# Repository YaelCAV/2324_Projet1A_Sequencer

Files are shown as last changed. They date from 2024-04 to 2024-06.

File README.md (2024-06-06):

# Projet-Sequenceur
> On souhaite créer un séquenceur musical qui émet des notes sur demande de l'utilisateur. Les notes doivent être variées et configurables, par exemple on souhaite pouvoir modifier leur hauteur, le nombre de répétitions par minute (bpm), et combiner les notes.
Pour cela on utilise sur conseil de l'un de nos professeurs un générateur de son programmable de Comodore 64 (dénomée MOS 6581) sortie en 1982.
La documentation de cette puce est facile d'accès et les possibilités qu'elle offrent satisfont nos exigences.
Comme mode de récupération du signal de sortie nous avons finalement choisi de proposer une sortie MIDI et Jack, il n'y a pas de haut-parleur intégré à notre séquenceur. L'alimentation de notre machine se fera par ailleurs via un port USB-C.

# Equipe
* Yael CAVAILLE-VOISIN
* Alexis NAUD
* Benoit LOMBARD
* Guilhem BOULARAN
* Louis GEORGE
> Rajouter vos github, linked in, etc...

# Journal de bord
> Déroulé séance par séance

## Séance 1 création du git, rédaction du cahier des charges et du plan, révision du cahier des charges.
## Séance 2 rendu du diagramme d'architecture, et des 3 bons de commande de composants, révision du cahier des charges et recherche des composants.
## Séance 3 CAO avec Kicad, changement de composants (boutons et LEDs RGB, hauts-parleurs, ampli audio).
## Séance 4 fin de conception du PCB et routage complet.
## Séance 5 récupération des composants et soudure, conception 3D, Architecture du code
## Séance 6 soudure + résolution des problèmes (d'empreinte des boutons-LED RG au lieu de RB via des PCB-adaptateurs imprimés à l'ENSEA), conception 3D
## Séance 7 soudure + résolution de problèmes, code, conception 3D
## Séance 8 soudure + résolution de problèmes, code, conception 3D
## Séance 9 code, présentation en séance, màj des livrables, résolution de problèmes liés au PCB et au processeur !
## Séance 10 code, création, compilation et vérification des livrables.

# Livrables
## PCB
> Présentation du schéma (grandes lignes) + PCB

## Code
> Architecture de votre code

## Rendu final
> Video ici de votre projet

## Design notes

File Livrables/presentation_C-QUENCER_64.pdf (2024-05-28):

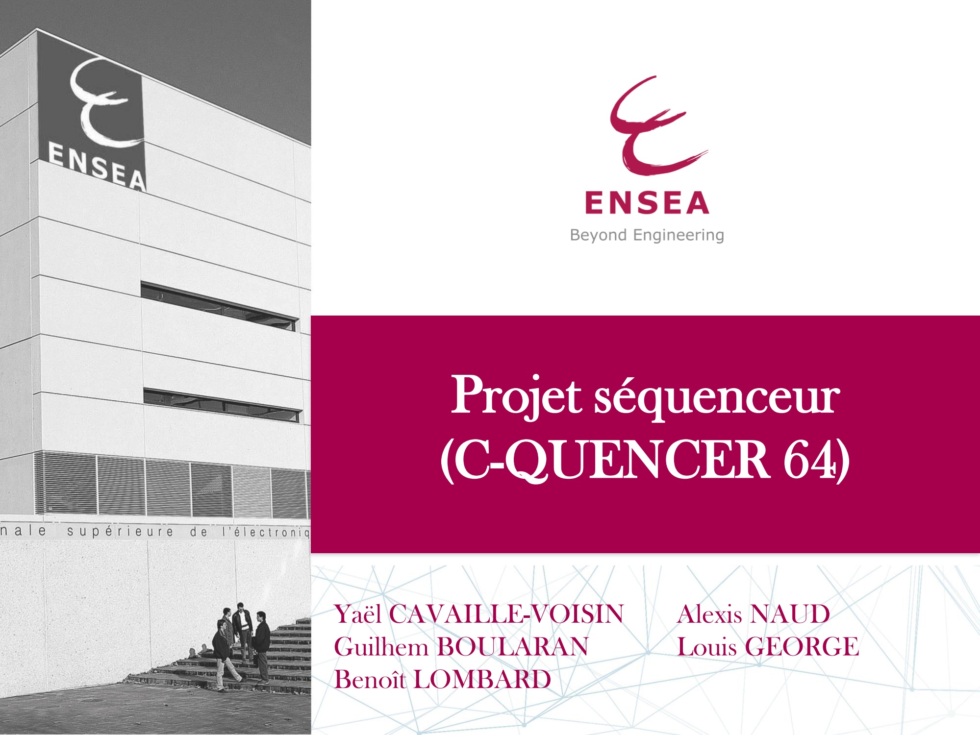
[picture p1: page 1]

# Projet séquenceur (C-QUENCER 64)

Yaël CAVAILLE-VOISIN | Alexis NAUD
Guilhem BOULARAN | Louis GEORGE

# Benoît LOMBARD

# TITRE DE PARAGRAPHE

# Concept & objectifs :

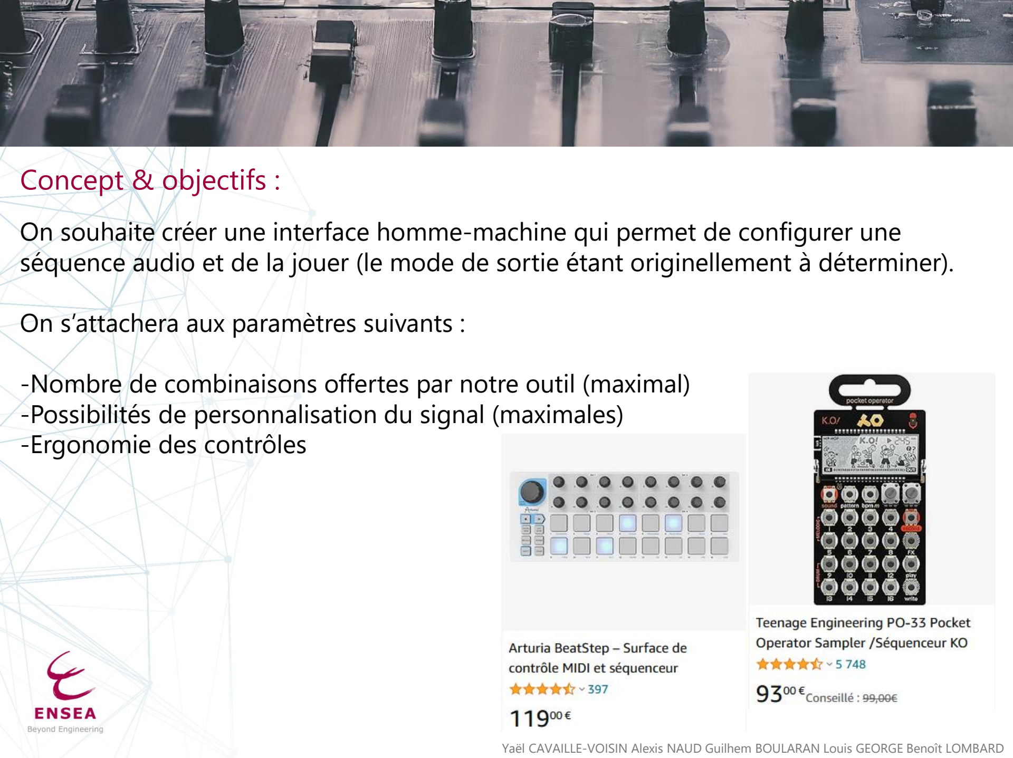
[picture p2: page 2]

# On souhaite créer une interface homme-machine qui permet de configurer une

séquence audio et de la jouer (le mode de sortie étant originellement à déterminer).

# On s’attachera aux paramètres suivants :

# -Nombre de combinaisons offertes par notre outil (maximal) -Possibilités de personnalisation du signal (maximales) -Ergonomie des contrôles

Yaël CAVAILLE-VOISIN Alexis NAUD Guilhem BOULARAN Louis GEORGE Benoît LOMBARD

# Cahier des charges du C-QUENCER 64 :

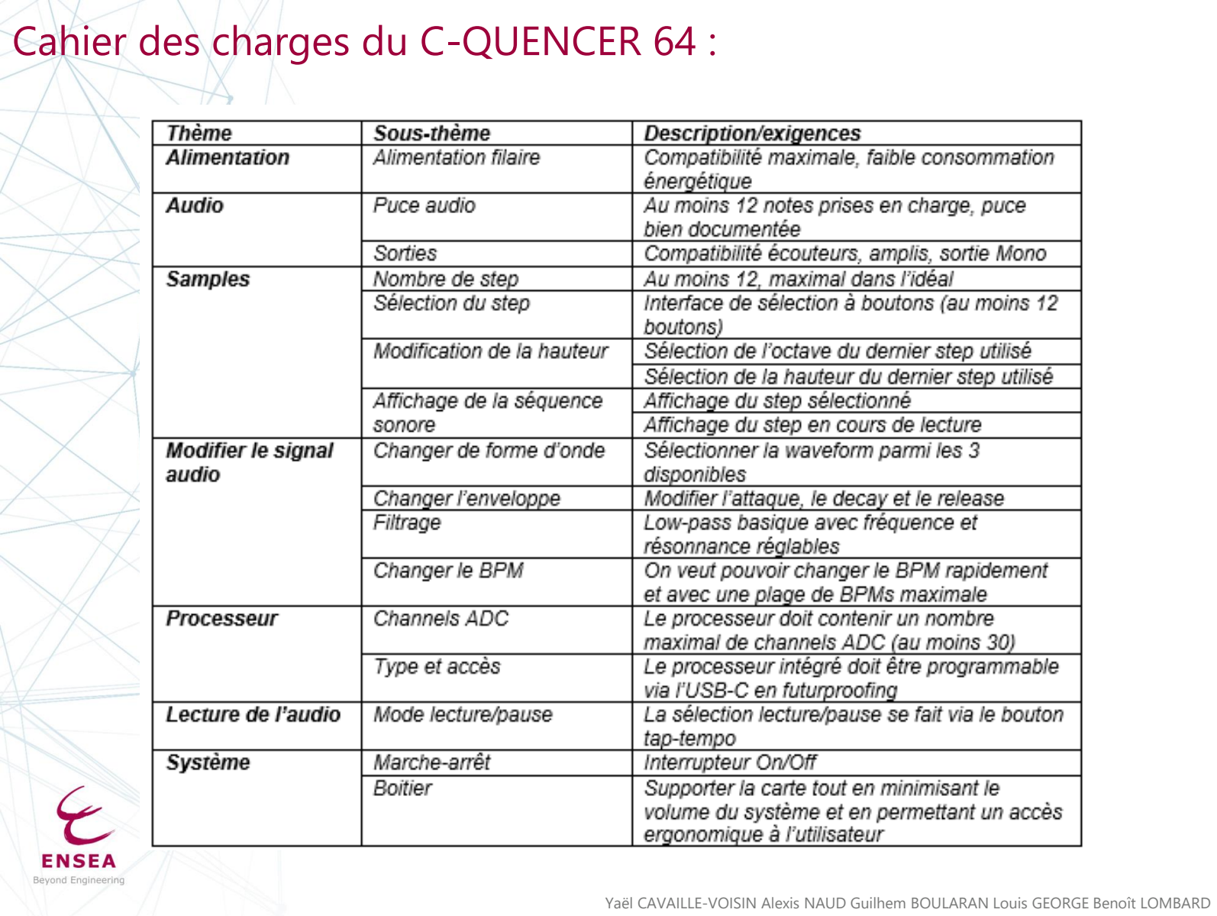
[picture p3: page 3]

# Répartition des Tâches & Déroulement du Projet :

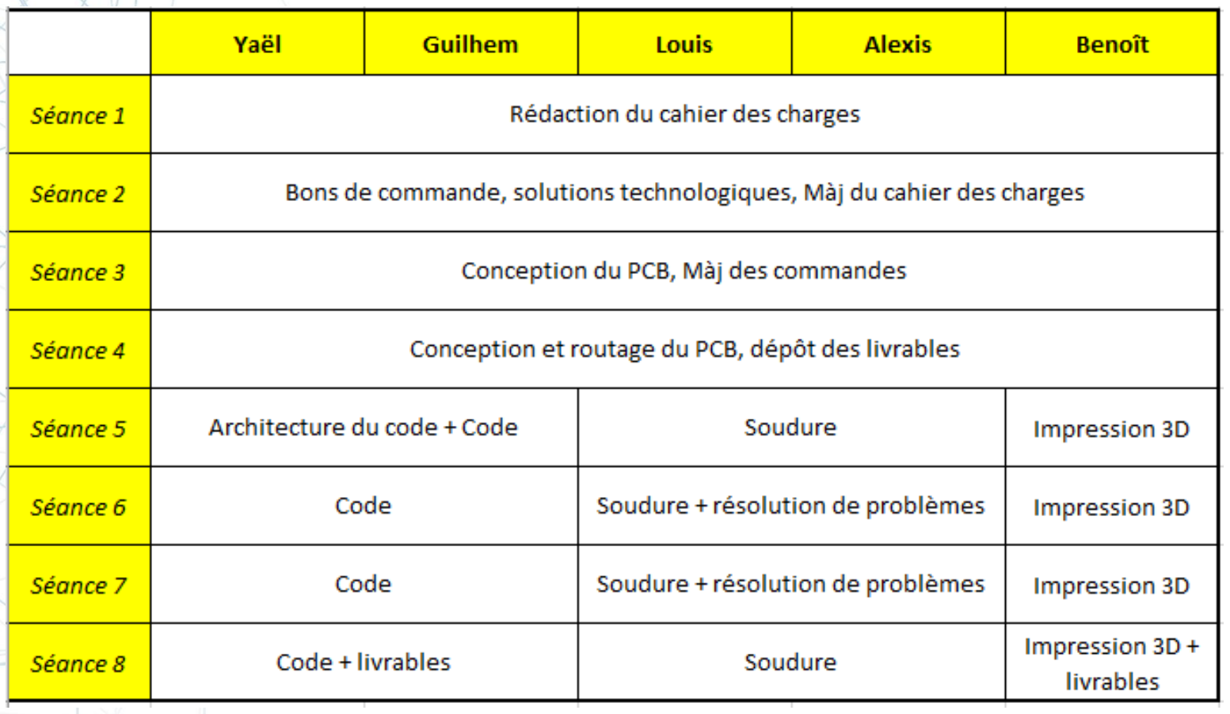
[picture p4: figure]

# Solutions techniques retenues pour le C-QUENCER 64 :

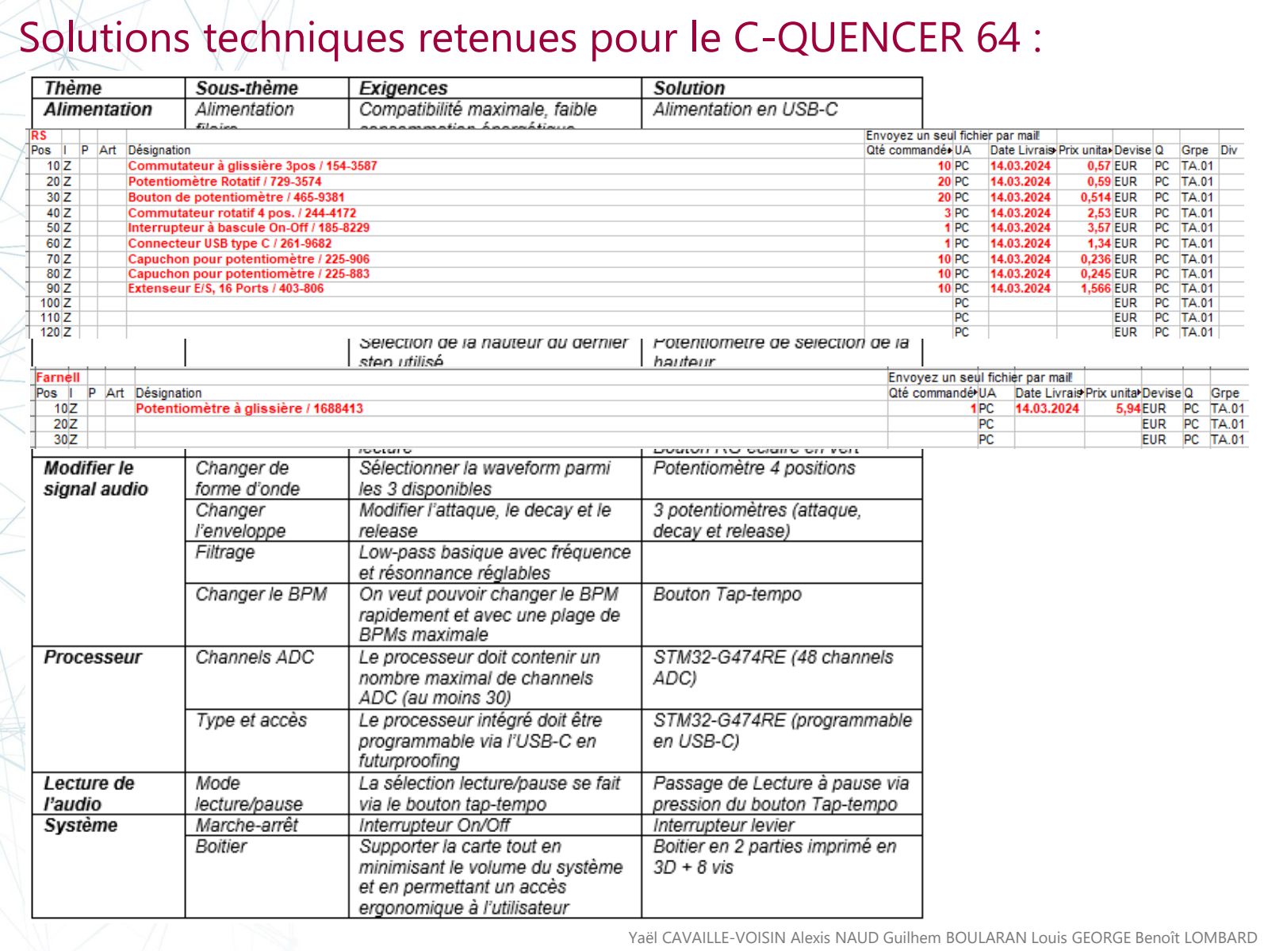
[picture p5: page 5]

# PCB 1/2 :

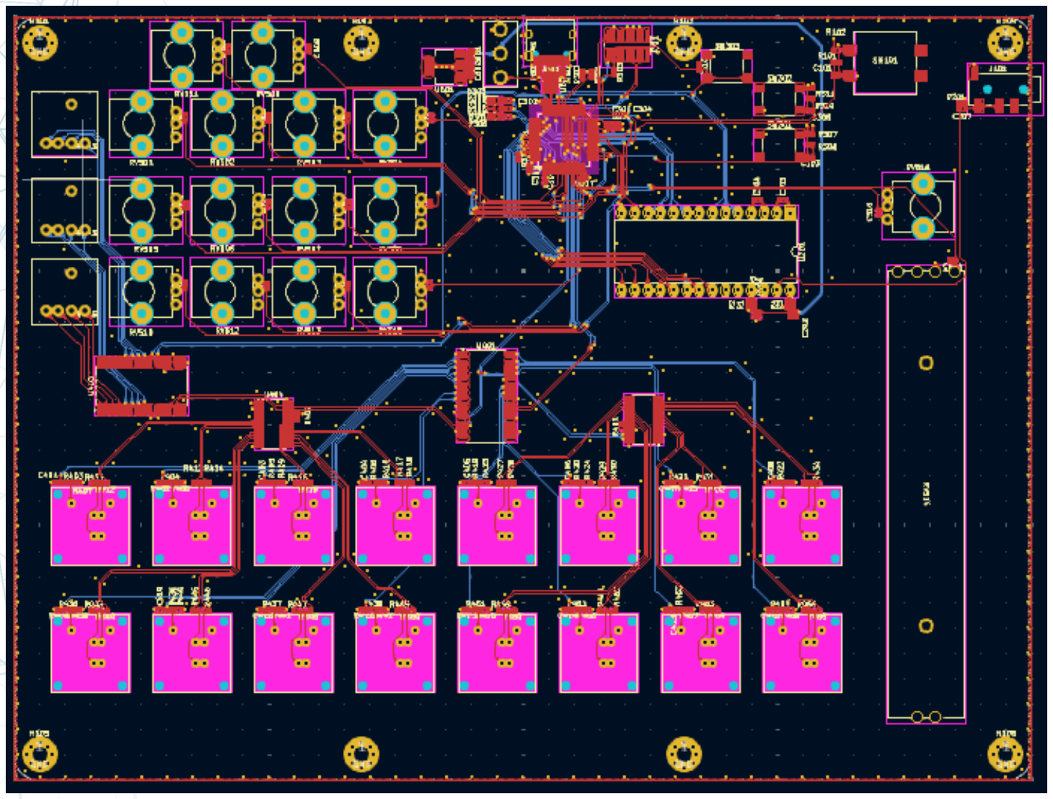
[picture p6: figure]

# PCB 1/2 :

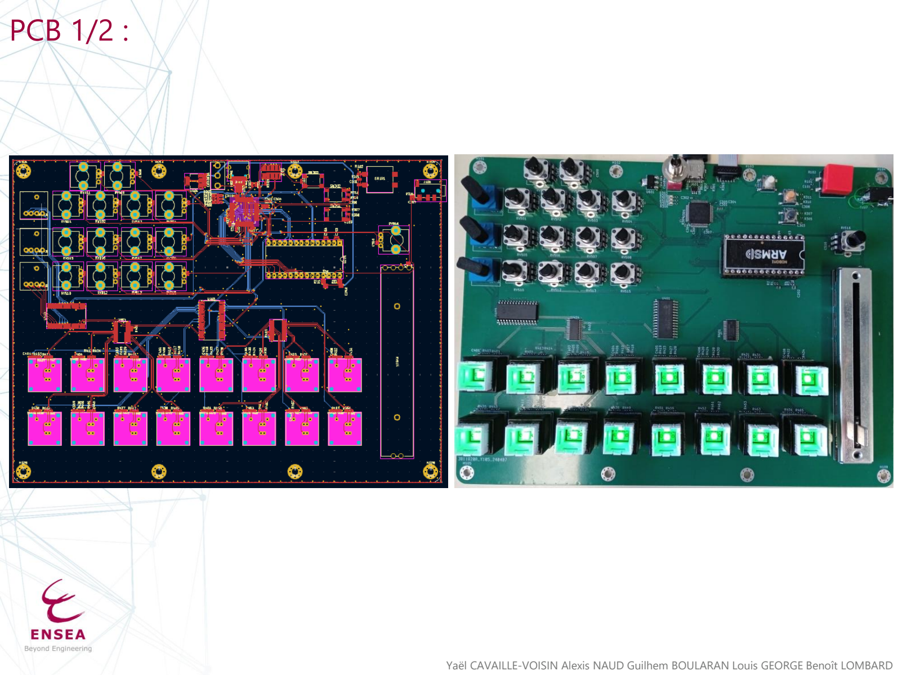
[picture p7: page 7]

# PCB 1/2 :

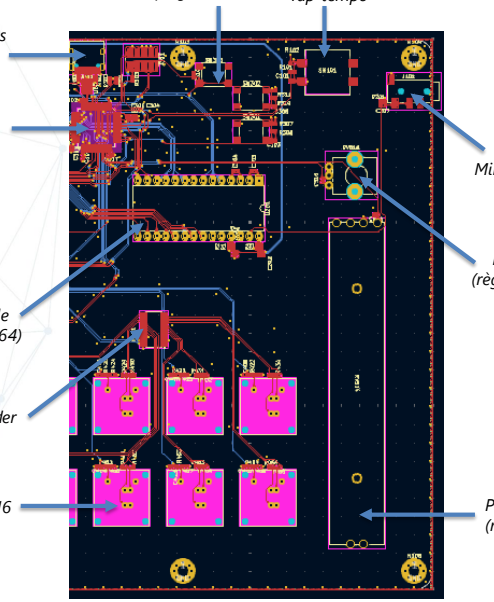
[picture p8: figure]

## Potentiomètre linéaire (règlage de la hauteur)

## Potentiomètre (règlage de l’octave)

## Sortie Mini-Jack 3.5

## Bouton Tap-tempo

### Boutons de programmation x3

## Alimentation et accès programmation du processeur (USB-C)

## Processeur STM32-G474RE

## Puce audio ARMSID simulation de MOS 6581 (Comodore 64)

## GPIO expender

## Bouton-LED RG x16

# PCB 2/2 :

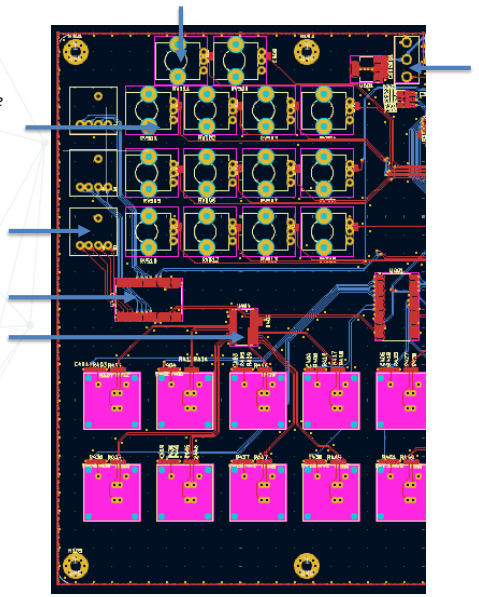
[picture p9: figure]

## Interrupteur général

## Sélecteur de waveformes (potentiomètre à crans x3)

## Potentiomètres d’enveloppe (attack, decay, release)

## Potentiomètres de filtre (fréquence et résonnance)

## LED Driver

## GPIO Expender

# Code :

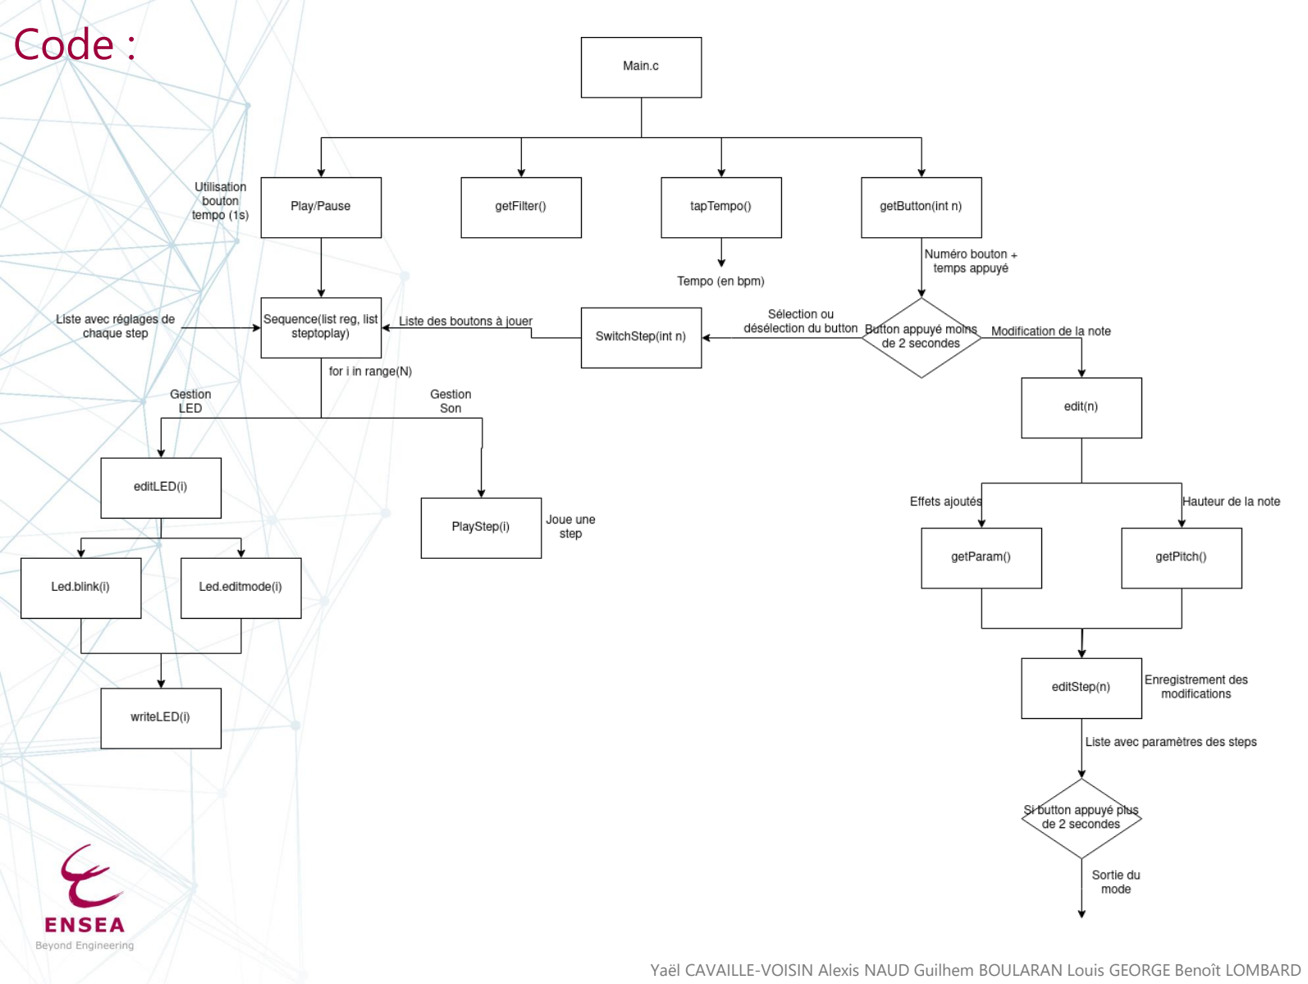
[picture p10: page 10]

# Code :

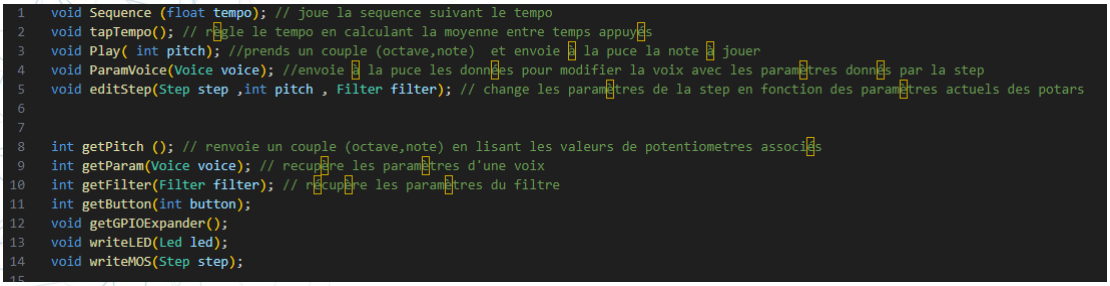
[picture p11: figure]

# Défis et solutions :

# - Erreur de WÜRT Electronik dans les commandes : bouton-LED RG au lieu de RB

donc problème d’empreinte avec le PCB.

# On a soudé des PCB-adaptateurs imprimés à l’ENSEA entre le PCB et les boutons-

LED RG.

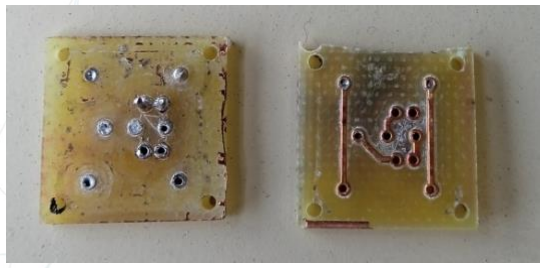
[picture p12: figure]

# - Quelques difficultés lors de la programmation, car les tensions des broches de la

puce audio ne correspondaient pas à ce qui est attendu d’après la documentation.

# Perspectives :

# - Manque de temps par rapport à la complexité du code à réaliser, il parrait difficile

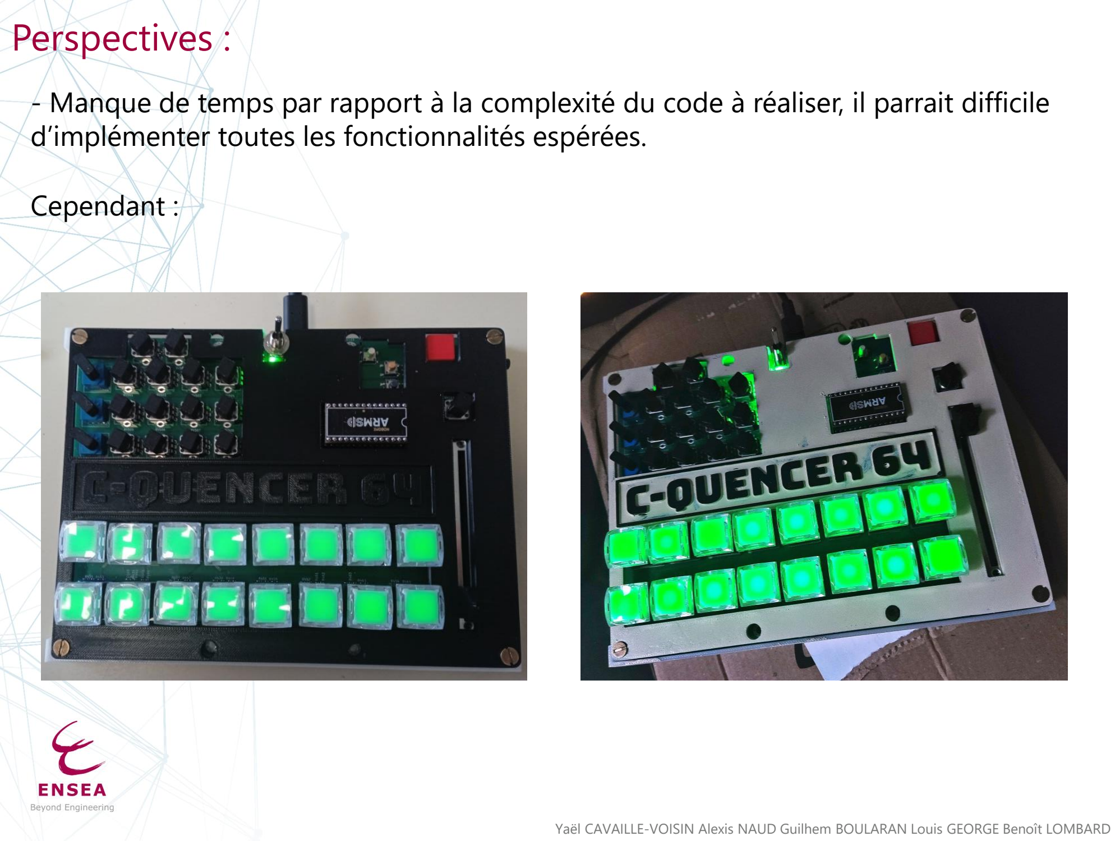
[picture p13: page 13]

d’implémenter toutes les fonctionnalités espérées.

# Cependant :

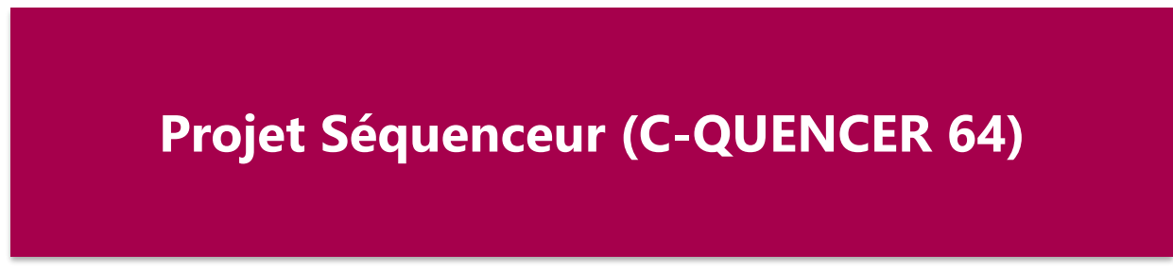
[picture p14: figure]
Projet Séquenceur (C-QUENCER 64)

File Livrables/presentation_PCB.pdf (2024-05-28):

## Présentation du PCB :

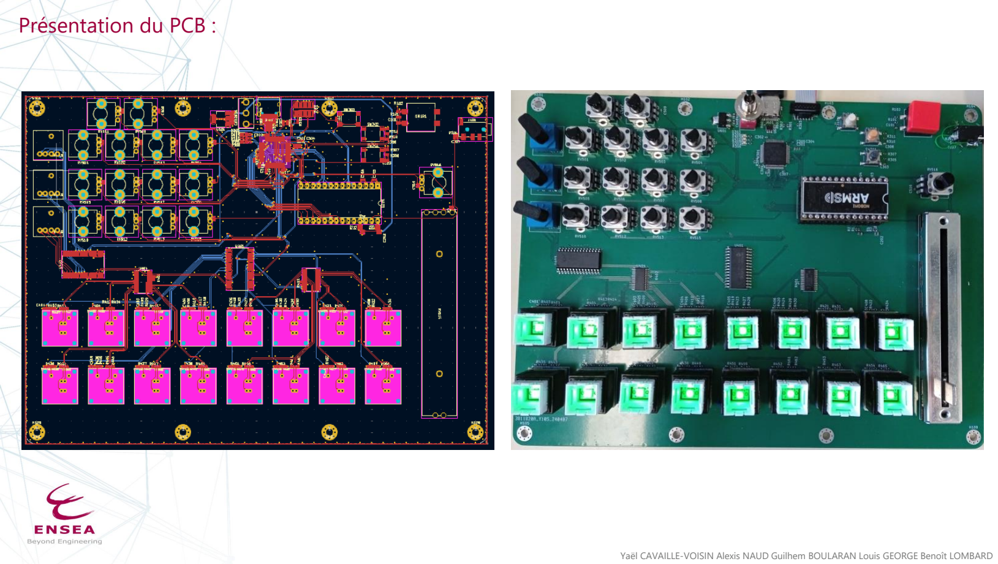
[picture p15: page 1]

Yaël CAVAILLE-VOISIN Alexis NAUD Guilhem BOULARAN Louis GEORGE Benoît LOMBARD

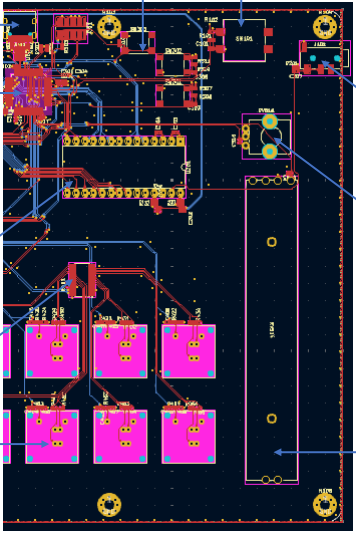
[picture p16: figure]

Potentiomètre linéaire
(règlage de la hauteur)

Potentiomètre
(règlage de l’octave)

Sortie
Mini-Jack 3.5

Bouton
Tap-tempo

Boutons de
programmation x3

Alimentation et accès
programmation du
processeur (USB-C)

Processeur
STM32-G474RE

Puce audio
ARMSID simulation de
MOS 6581 (Comodore 64)

GPIO expender

Bouton-LED RG x16

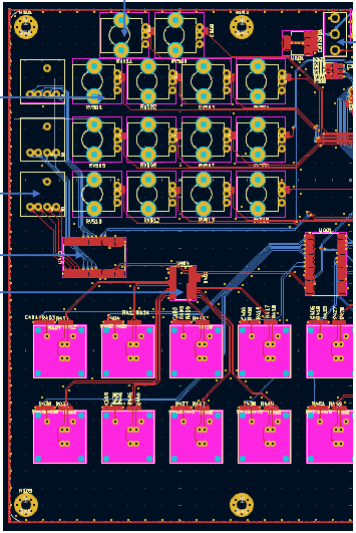
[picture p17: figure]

Interrupteur général

Sélecteur de waveformes
(potentiomètre à crans x3)

Potentiomètres d’enveloppe (attack, decay, release)

Potentiomètres de filtre
(fréquence et résonnance)

LED Driver

GPIO Expender

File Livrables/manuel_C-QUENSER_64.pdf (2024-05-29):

### Manuel d’utilisation du C-QUENCER 64

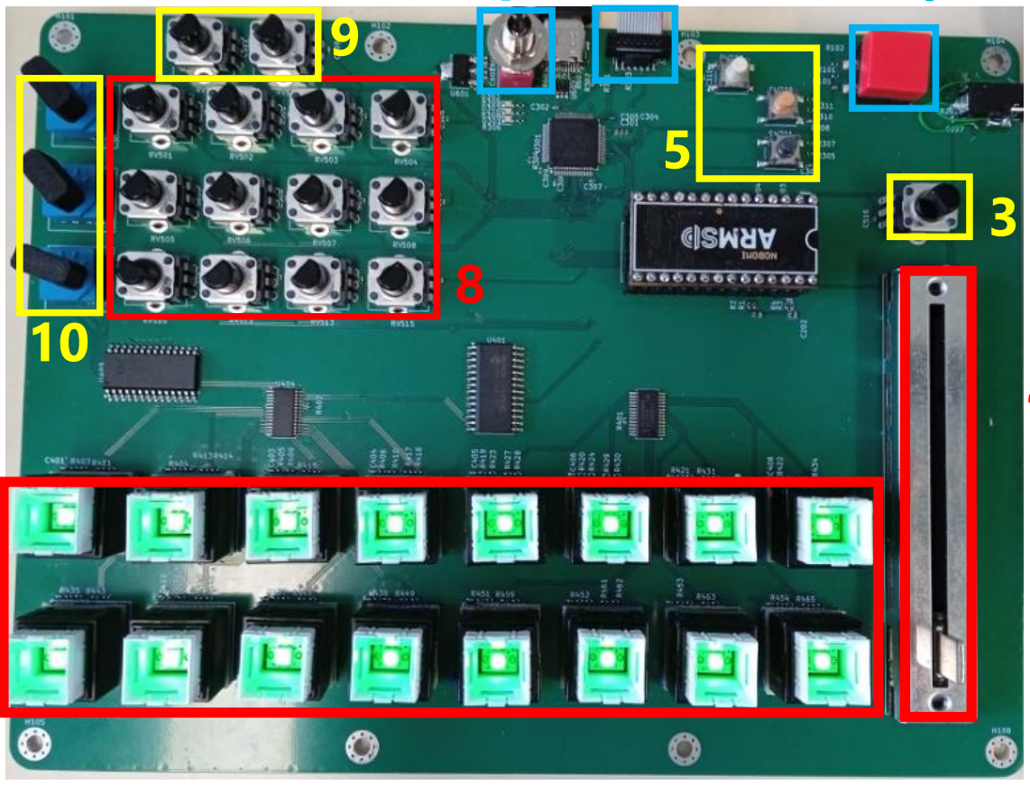
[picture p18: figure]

1. 16 Boutons d’activation des steps, l’appui permet d’activer ou désactiver les steps.
2. Potentiomètre linéaire de réglage de la hauteur du step sélectionné.
3. Potentiomètre d’octave, permet de régler l’octave du step sélectionné.
4. Bouton tap-tempo : calcule le temps moyen entre deux activations du bouton et en extrait le BPM qui cadencera la séquence de notes. Un seul appui sur le bouton tap-tempo permet de passer du mode lecture au mode pause (et inversement), lors d’un nouvel appui.
5. 3 Boutons servant à la programmation du processeur (ne sont pas destinés à l’acheteur).
6. Port USB-C servant à l’alimentation et à la programmation du processeur.
7. Interrupteur général du séquenceur.
8. 12 Potentiomètres de sélection des valeurs du : pulse-width (rapport cyclique) (utilisable uniquement pour le signal créneau), attack, decay, et release (de gauche à droite suivant une ligne). Chaque ligne représente une voie, la puce audio peut donc prendre en charge 3 voies simultanément.
9. 2 Potentiomètres de configuration du filtre passe-bas : à gauche le potentiomètre détermine la fréquence de coupure, à droite il détermine la résonnance.
10. Potentiomètre à crans permettant la sélection du type de forme d’onde (Sinus, créneau, triangle ou bruit).

1

2

4

7 6

Utilisation du C-QUENSER 64 :

1. Activer un step via un appui sur l’un des 16 boutons poussoirs «RGB» (1).
2. Configurer les formes d’ondes de ce step via les potentiomètres à crans (10) puis régler le band-width, attack, decay et release (8). Régler l’octave (3) et la hauteur (2), l’ordre dans lequel sont faits ces réglages est indifférent, ils seront appliqués au dernier step qui a été activé uniquement.
3. Répéter les étapes 1 et 2 pour chaque step souhaité et pour le nombre de steps souhaités.
4. On peut ensuite changer le BPM (4) et/ou paramétrer un filtre passe-bas via les 2 potentiomètres (9), ces paramètres sont des paramètres globaux qui sont appliqués à tous les steps activés. Les paramètres Globaux peuvent aussi être appliqués ou configurés en amont, cela ne changera pas la production finale, l’utilisateur est invité à employer la méthode qu’il juge la plus performante.

L’utilisation du C-QUENCER 64 nécessite qu’il soit alimenté via l’USB-C (6).

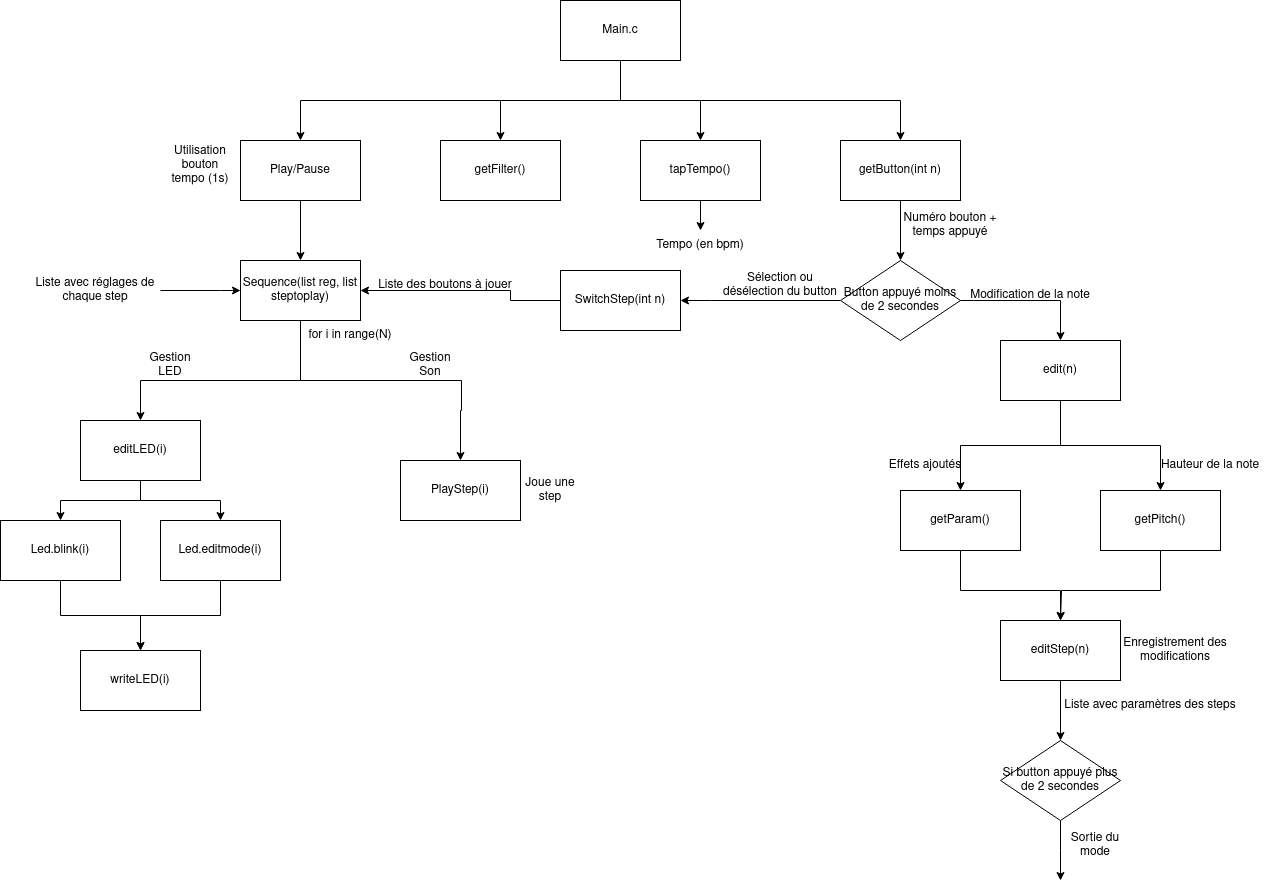
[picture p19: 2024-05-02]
Fonctionnement_sequencer.png

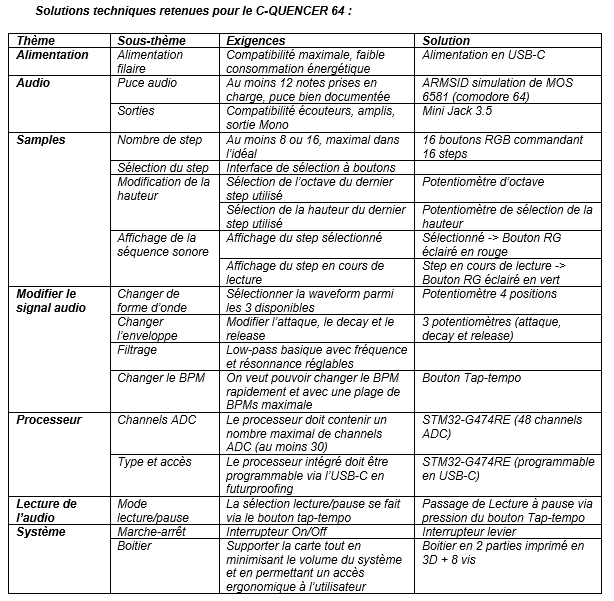
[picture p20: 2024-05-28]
Livrables/cahier_des_charges.png

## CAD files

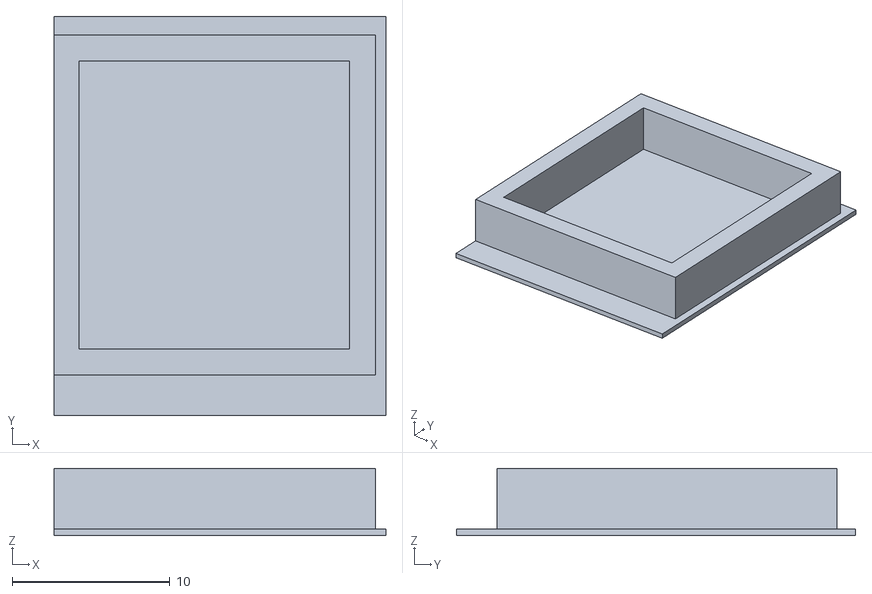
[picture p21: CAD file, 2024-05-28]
3D/cache_sequenceur v3.stl
21.0 x 25.3 x 4.25

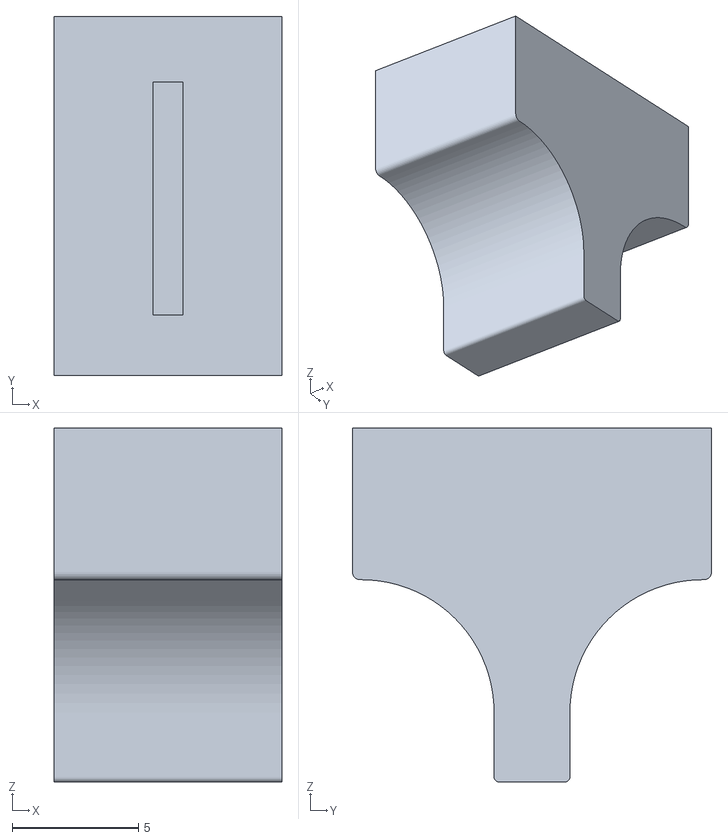
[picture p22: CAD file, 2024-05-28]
3D/capuchon_potar_lineaire_sequenceur v7.stl
9.00 x 14.2 x 14.0

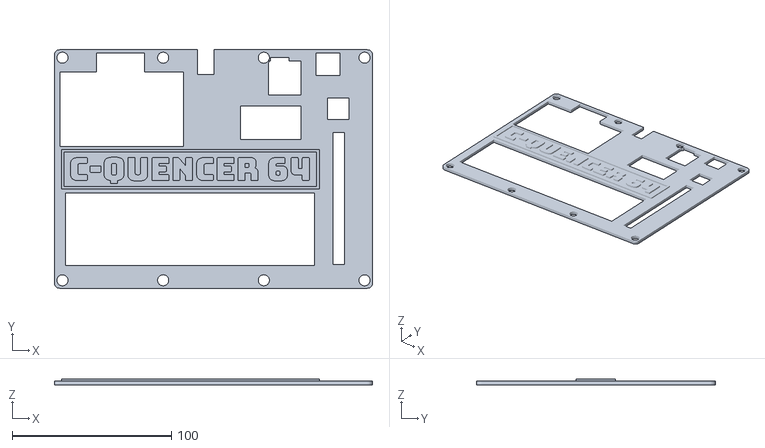
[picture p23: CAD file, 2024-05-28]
3D/couvercle_sequenceur v16.stl
200.0 x 150.0 x 4.00

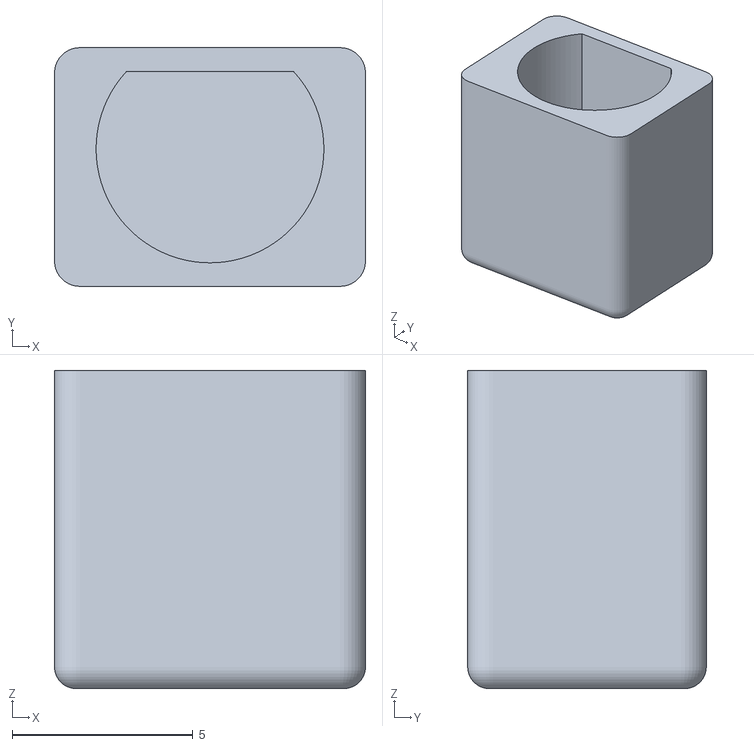
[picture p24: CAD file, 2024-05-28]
3D/potentio_sequenceur v3.stl
8.60 x 6.60 x 8.80

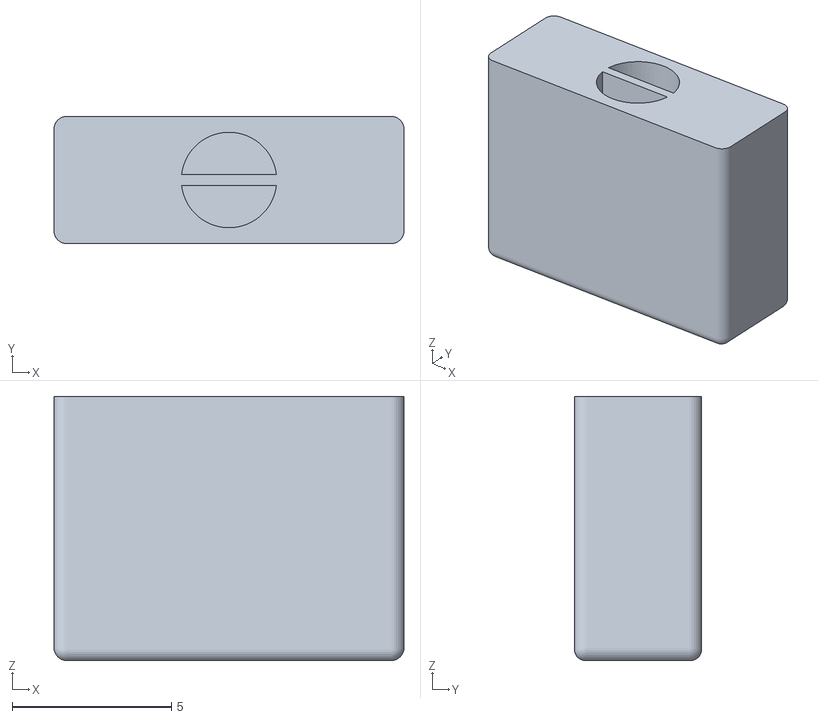
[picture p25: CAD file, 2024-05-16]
3D/capuchon_wave_sequenceur v2.stl
11.0 x 4.00 x 8.30

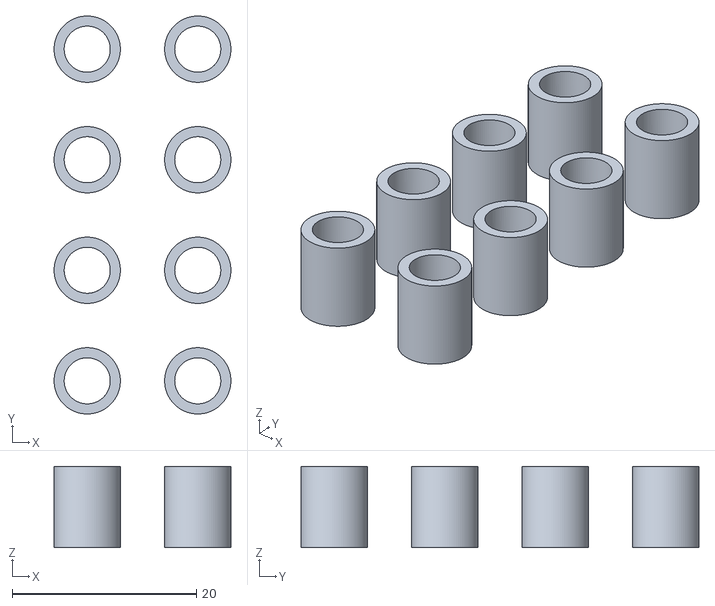
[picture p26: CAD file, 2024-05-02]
3D/Joints sequenceur.stl
19.2 x 43.2 x 8.80

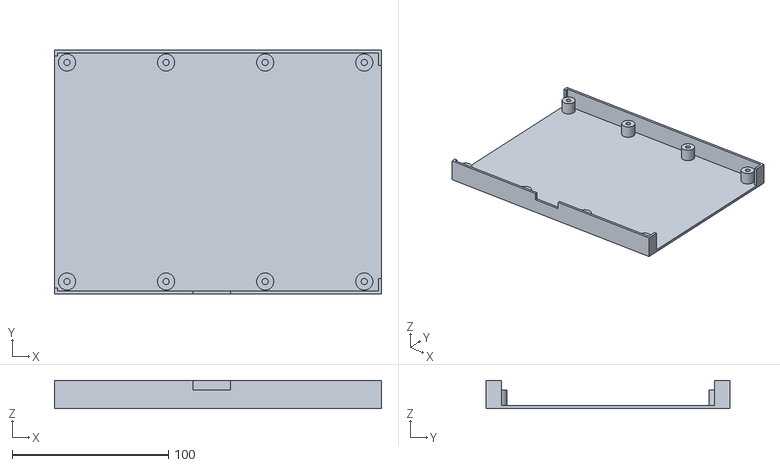
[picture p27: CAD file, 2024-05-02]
3D/Boitier_sequenceur v6.stl
209.0 x 156.0 x 18.0

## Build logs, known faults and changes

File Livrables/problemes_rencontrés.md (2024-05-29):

# Problèmes C-QUENCER_64 :
## Au niveaux des I2C : On a un inversé SCL et Sdata
-> Solution = On coupe les pistes et on rajoute des fils pour échanger les pistes.
## Aucun signal Horloge ne sort de la broche PG10 de la puce audio, au lieu de cela un signal Horloge sort de la broche PA8 lorsqu’on programme PG10 comme sortie du signal d’horloge.
-> Solution = on coupe la piste liée à PA8 et on récupère le signal Horloge via un fil.
## Impossible d’implémenter un DFU car il manque une patte sur la puce audio.
## On a refait un socket sur la puce car 2 pattes avaient été cassées.

# Améliorations pour C-QUENCER_64v2 :
## L’ajout d’un signal de synchronisation IN-OUT (clock externe), ce signal définit le BPM de notre retour.
## Ajout d'un bouton de sélection des pistes, car pour le moment on doit appuyer sur le tap-tempo pour sélectionner le signal à modifier, ce qui met sur pause le retour.
## Utiliser des touches de clavier mécanique «cherry-MX» comme bouton RGB, en mettant des Leds RGB dedans. Afin de réduire le coût des boutons, et d’optimiser la course des boutons (meilleure ergonomie).
## Bouton tap-tempo : changer le modèle du bouton pour un bouton avec une pression d’enclanchement moins importante.
## Inclure un haut-parleur sans amplificateur dans la prochaine version du PCB, il lui sera fourni le même signal que la sortie mini-jack 3.5, l’intérêt est d’avoir un retour imédiat de la sortie (savoir si on a un son ou non).
## Inclure dans la prochaine version du PCB, une led qui clignotte à même fréquence que le BPM.
## Inclure dans la prochaine version du PCB, une sortie MIDI, pour répondre à la forte demande consomateur.

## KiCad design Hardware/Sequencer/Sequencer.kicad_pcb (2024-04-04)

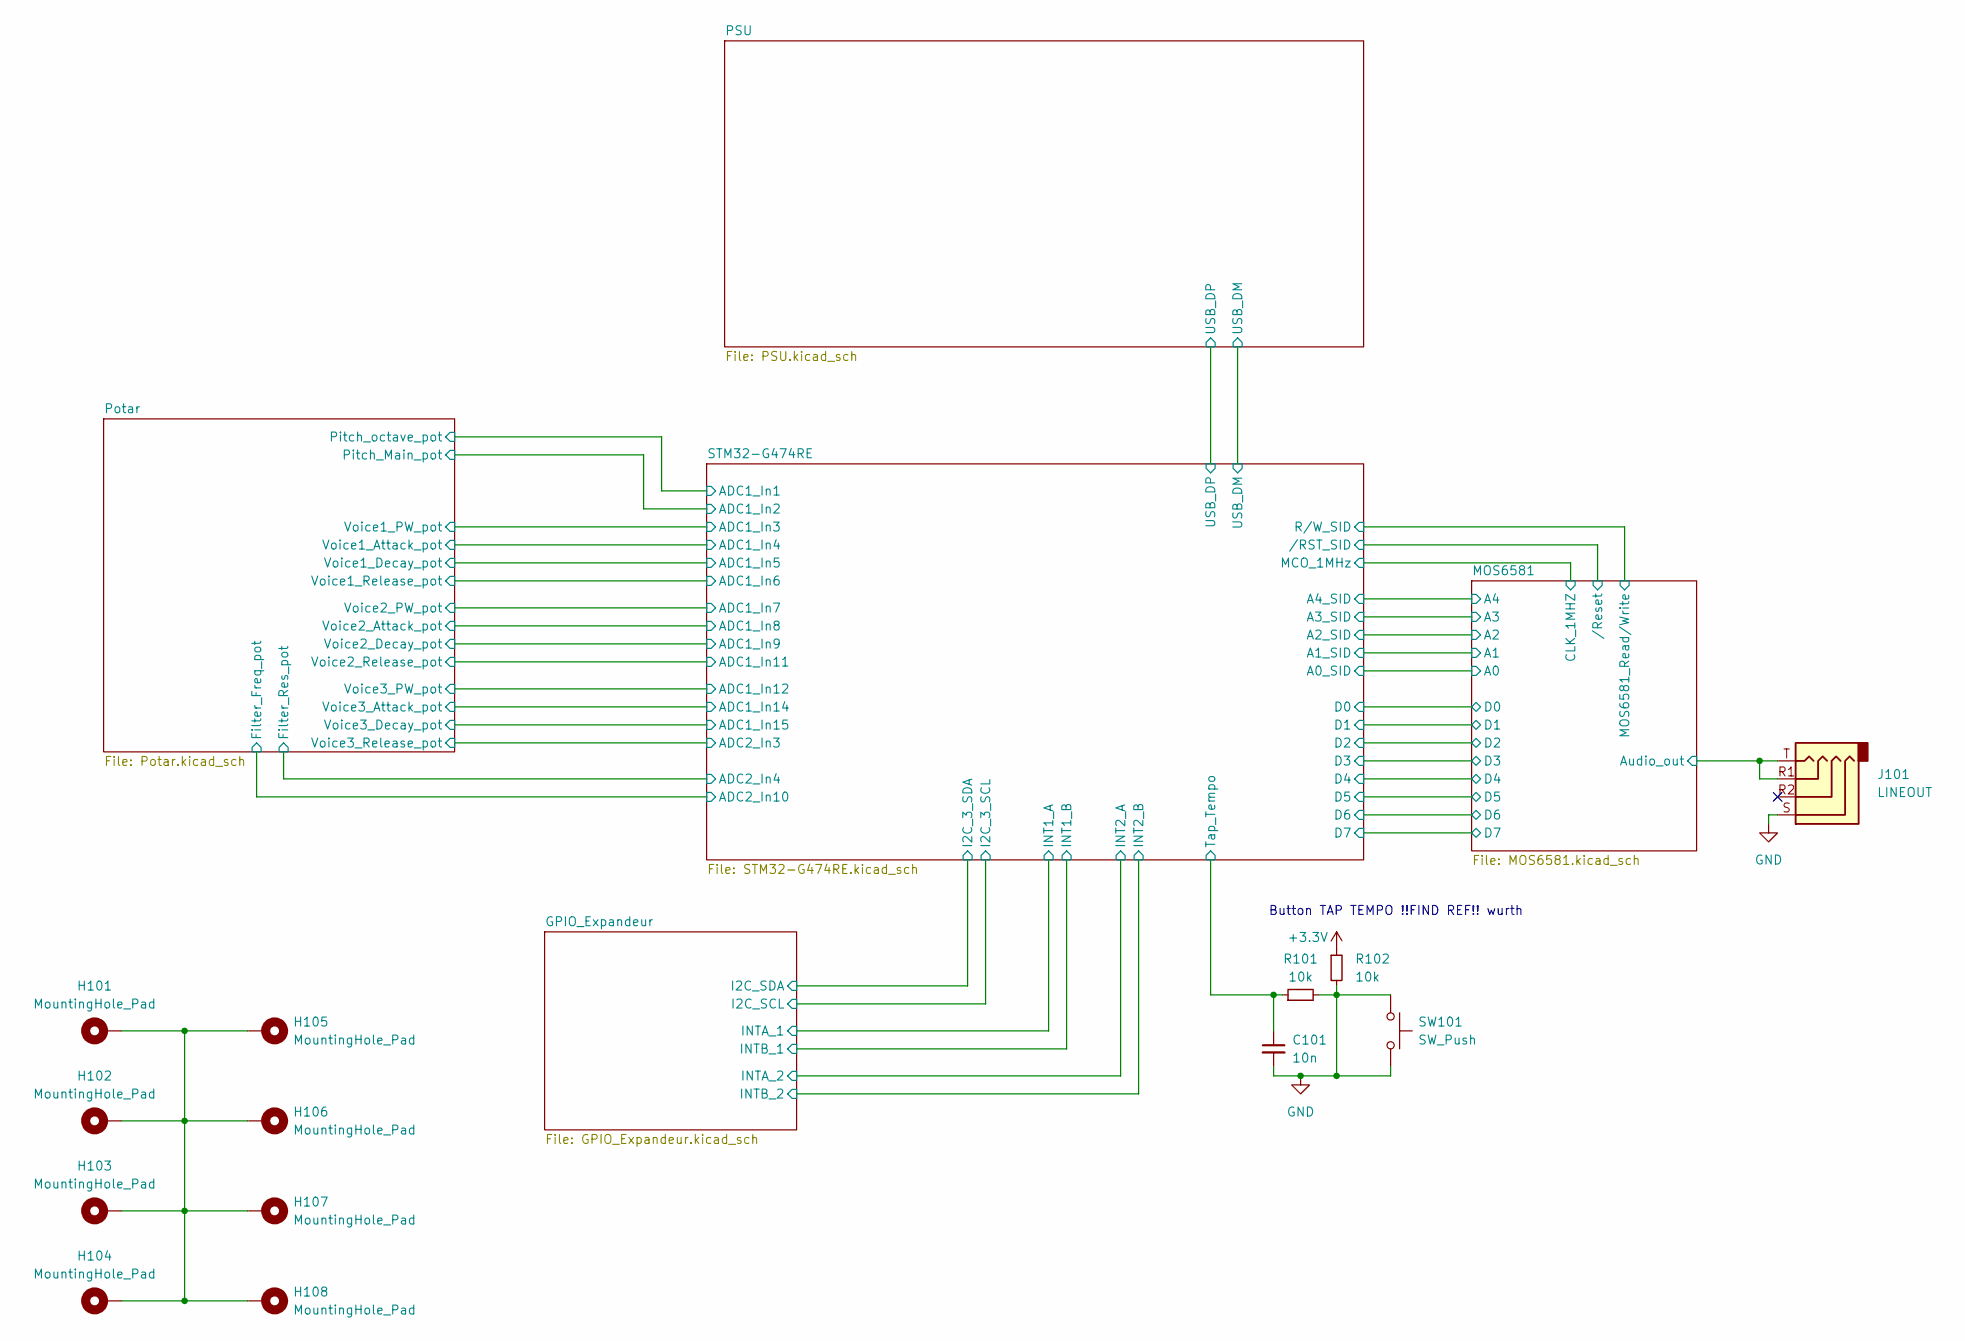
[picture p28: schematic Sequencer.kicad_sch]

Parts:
C101: 10n; C_0402_1005Metric
H101, H102, H103, H104, H105, H106, H107, H108: MountingHole_Pad; MountingHole_3.2mm_M3_Pad_Via
J101: LINEOUT; Jack_3.5mm_PJ320D_Horizontal; LCSC Part C431535
R101, R102: 10k; R_0402_1005Metric
SW101: SW_Push; SMT Push Button 12x12

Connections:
+3.3V: R102.1; also elsewhere on the board
/MOS6581/Audio_out: J101.R1, J101.T; also elsewhere on the board
/STM32-G474RE/Tap_Tempo: C101.1, R101.1; also elsewhere on the board
GND: C101.2, J101.S, R101.2, R102.2, SW101.1, SW101.2; also elsewhere on the board
unnamed: H101.1, H102.1, H103.1, H104.1, H105.1, H106.1, H107.1, H108.1

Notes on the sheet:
Button TAP TEMPO !!FIND REF!! wurth

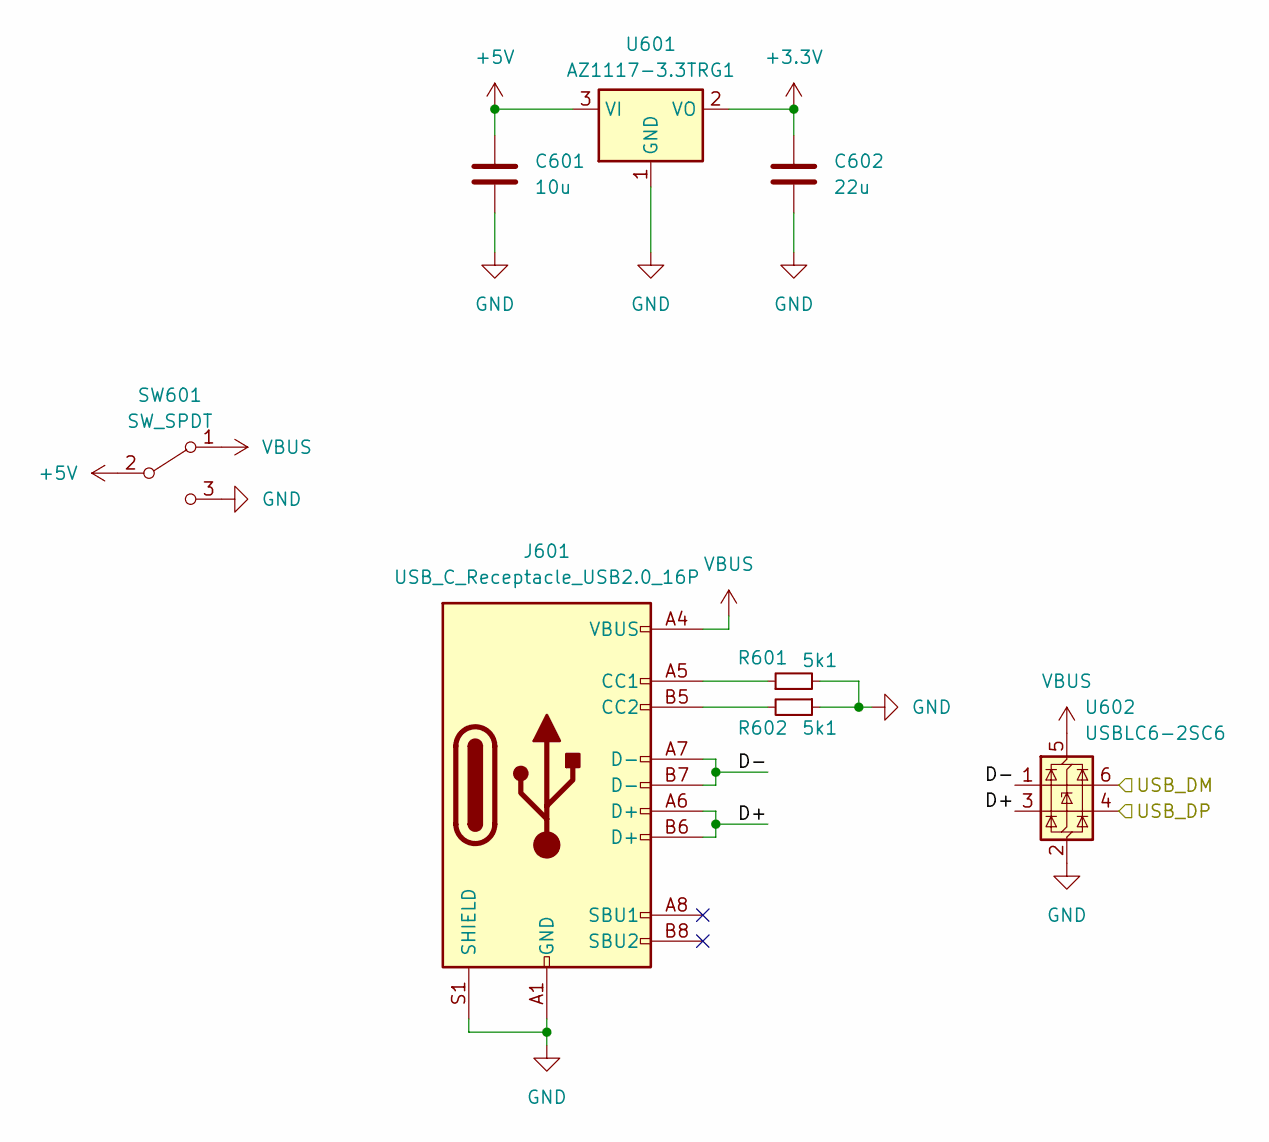
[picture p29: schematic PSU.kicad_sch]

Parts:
C601: 10u; C_0603_1608Metric
C602: 22u; C_0603_1608Metric
J601: USB_C_Receptacle_USB2.0_16P; USB_C_Receptacle_HRO_TYPE-C-31-M-12
R601, R602: 5k1; R_0402_1005Metric
SW601: SW_SPDT; 472121010111; MPN 472121010111
U601: AZ1117-3.3TRG1; SOT-223-3_TabPin2
U602: USBLC6-2SC6; SOT-23-6

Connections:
+3.3V: C602.1, U601.2 (VO); also elsewhere on the board
+5V: C601.1, SW601.2 (B), U601.3 (VI); also elsewhere on the board
/PSU/D+: J601.A6 (D+), J601.B6 (D+), U602.3 (I/O2)
/PSU/D-: J601.A7 (D-), J601.B7 (D-), U602.1 (I/O1)
/PSU/USB_DM: U602.6 (I/O1); also elsewhere on the board
/PSU/USB_DP: U602.4 (I/O2); also elsewhere on the board
GND: C601.2, C602.2, J601.A1 (GND), J601.A12 (GND), J601.B1 (GND), J601.B12 (GND), J601.S1 (SHIELD), R601.2, R602.1, SW601.3 (C), U601.1 (GND), U602.2 (GND); also elsewhere on the board
unnamed: J601.A5 (CC1), R601.1
unnamed: J601.B5 (CC2), R602.2
VBUS: J601.A4 (VBUS), J601.A9 (VBUS), J601.B4 (VBUS), J601.B9 (VBUS), SW601.1 (A), U602.5 (VBUS)

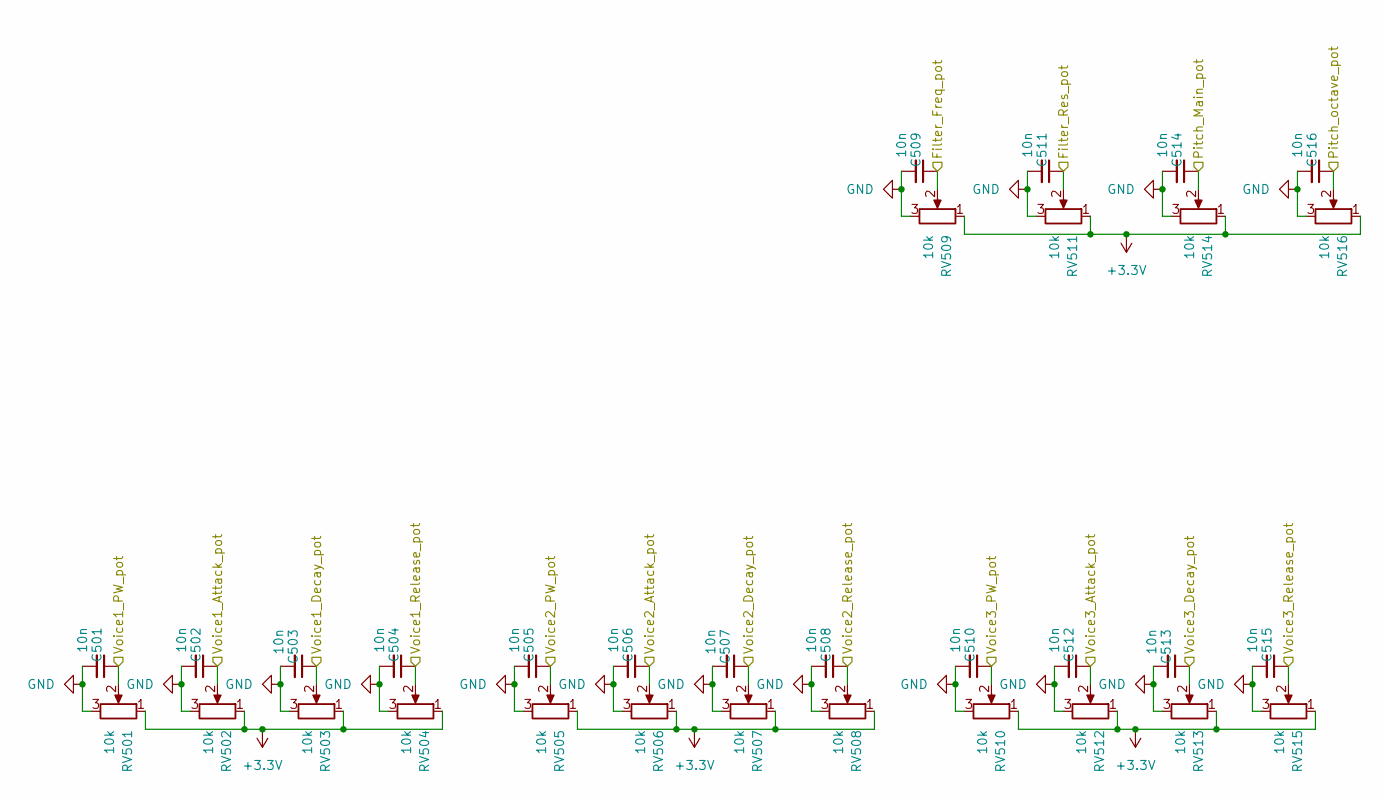
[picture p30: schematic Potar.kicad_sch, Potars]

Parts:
C501, C502, C503, C504, C505, C506, C507, C508, C509, C510, C511, C512, C513, C514, C515, C516: 10n; C_0402_1005Metric
RV501, RV502, RV503, RV504, RV505, RV506, RV507, RV508, RV509, RV510, RV511, RV512, RV513, RV515, RV516: 10k; Potentiometer_Alps_RK09K_Horizontal_CORRECTED
RV514: 10k; PTB6044-2010BPA103_BRN

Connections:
+3.3V: RV501.1, RV502.1, RV503.1, RV504.1, RV505.1, RV506.1, RV507.1, RV508.1, RV509.1, RV510.1, RV511.1, RV512.1, RV513.1, RV514.1, RV515.1, RV516.1; also elsewhere on the board
/Potar/Filter_Freq_pot: C509.1, RV509.2; also elsewhere on the board
/Potar/Filter_Res_pot: C511.1, RV511.2; also elsewhere on the board
/Potar/Pitch_Main_pot: C514.1, RV514.2; also elsewhere on the board
/Potar/Pitch_octave_pot: C516.1, RV516.2; also elsewhere on the board
/Potar/Voice1_Attack_pot: C502.1, RV502.2; also elsewhere on the board
/Potar/Voice1_Decay_pot: C503.1, RV503.2; also elsewhere on the board
/Potar/Voice1_PW_pot: C501.1, RV501.2; also elsewhere on the board
/Potar/Voice1_Release_pot: C504.1, RV504.2; also elsewhere on the board
/Potar/Voice2_Attack_pot: C506.1, RV506.2; also elsewhere on the board
/Potar/Voice2_Decay_pot: C507.1, RV507.2; also elsewhere on the board
/Potar/Voice2_PW_pot: C505.1, RV505.2; also elsewhere on the board
/Potar/Voice2_Release_pot: C508.1, RV508.2; also elsewhere on the board
/Potar/Voice3_Attack_pot: C512.1, RV512.2; also elsewhere on the board
/Potar/Voice3_Decay_pot: C513.1, RV513.2; also elsewhere on the board
/Potar/Voice3_PW_pot: C510.1, RV510.2; also elsewhere on the board
/Potar/Voice3_Release_pot: C515.1, RV515.2; also elsewhere on the board
GND: C501.2, C502.2, C503.2, C504.2, C505.2, C506.2, C507.2, C508.2, C509.2, C510.2, C511.2, C512.2, C513.2, C514.2, C515.2, C516.2, RV501.3, RV502.3, RV503.3, RV504.3, RV505.3, RV506.3, RV507.3, RV508.3, RV509.3, RV510.3, RV511.3, RV512.3, RV513.3, RV514.3, RV515.3, RV516.3; also elsewhere on the board

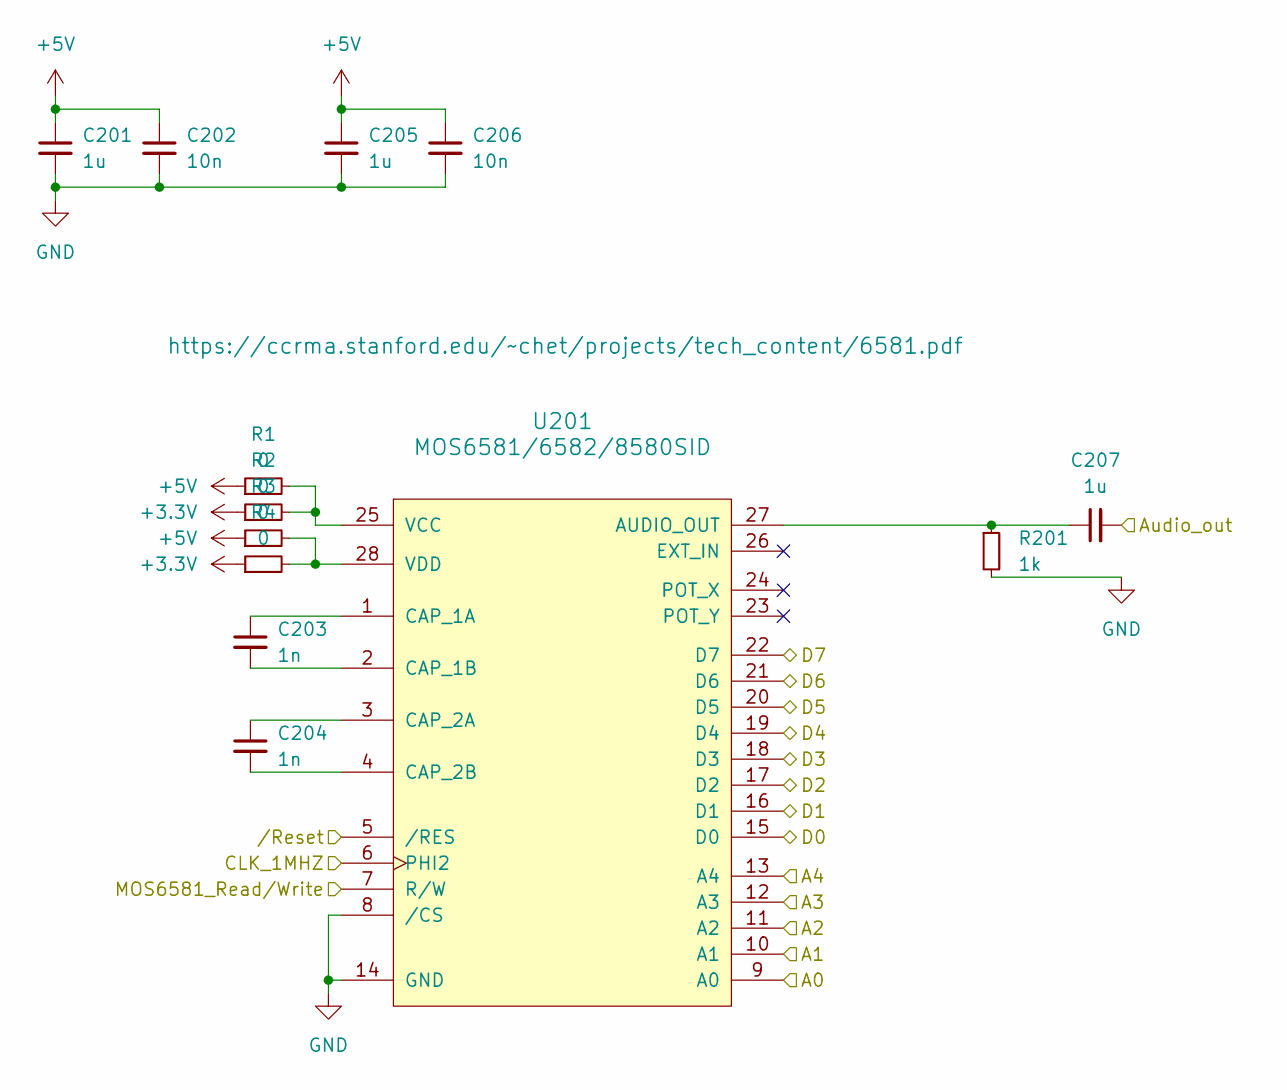
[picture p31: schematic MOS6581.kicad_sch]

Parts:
C201, C205, C207: 1u; C_0402_1005Metric
C202, C206: 10n; C_0402_1005Metric
C203, C204: 1n; C_0402_1005Metric
R1, R2, R3, R4: 0; R_0402_1005Metric
R201: 1k; R_0402_1005Metric
U201: MOS6581/6582/8580SID; DIP-28_W15.24mm_LongPads

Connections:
+3.3V: R2.1, R4.1; also elsewhere on the board
+5V: C201.1, C202.1, C205.1, C206.1, R1.1, R3.1; also elsewhere on the board
/MOS6581/A0: U201.9 (A0); also elsewhere on the board
/MOS6581/A1: U201.10 (A1); also elsewhere on the board
/MOS6581/A2: U201.11 (A2); also elsewhere on the board
/MOS6581/A3: U201.12 (A3); also elsewhere on the board
/MOS6581/A4: U201.13 (A4); also elsewhere on the board
/MOS6581/Audio_out: C207.2; also elsewhere on the board
/MOS6581/D0: U201.15 (D0); also elsewhere on the board
/MOS6581/D1: U201.16 (D1); also elsewhere on the board
/MOS6581/D2: U201.17 (D2); also elsewhere on the board
/MOS6581/D3: U201.18 (D3); also elsewhere on the board
/MOS6581/D4: U201.19 (D4); also elsewhere on the board
/MOS6581/D5: U201.20 (D5); also elsewhere on the board
/MOS6581/D6: U201.21 (D6); also elsewhere on the board
/MOS6581/D7: U201.22 (D7); also elsewhere on the board
/MOS6581/MOS6581_Read/Write: U201.7 (R/W); also elsewhere on the board
/MOS6581//Reset: U201.5 (/RES); also elsewhere on the board
/STM32-G474RE/NRST: U201.6 (PHI2); also elsewhere on the board
GND: C201.2, C202.2, C205.2, C206.2, R201.2, U201.8 (/CS), U201.14 (GND); also elsewhere on the board
unnamed: C207.1, R201.1, U201.27 (AUDIO_OUT)
unnamed: C203.1, U201.1 (CAP_1A)
unnamed: C203.2, U201.2 (CAP_1B)
unnamed: C204.1, U201.3 (CAP_2A)
unnamed: C204.2, U201.4 (CAP_2B)
unnamed: R1.2, R2.2, U201.25 (VCC)
unnamed: R3.2, R4.2, U201.28 (VDD)

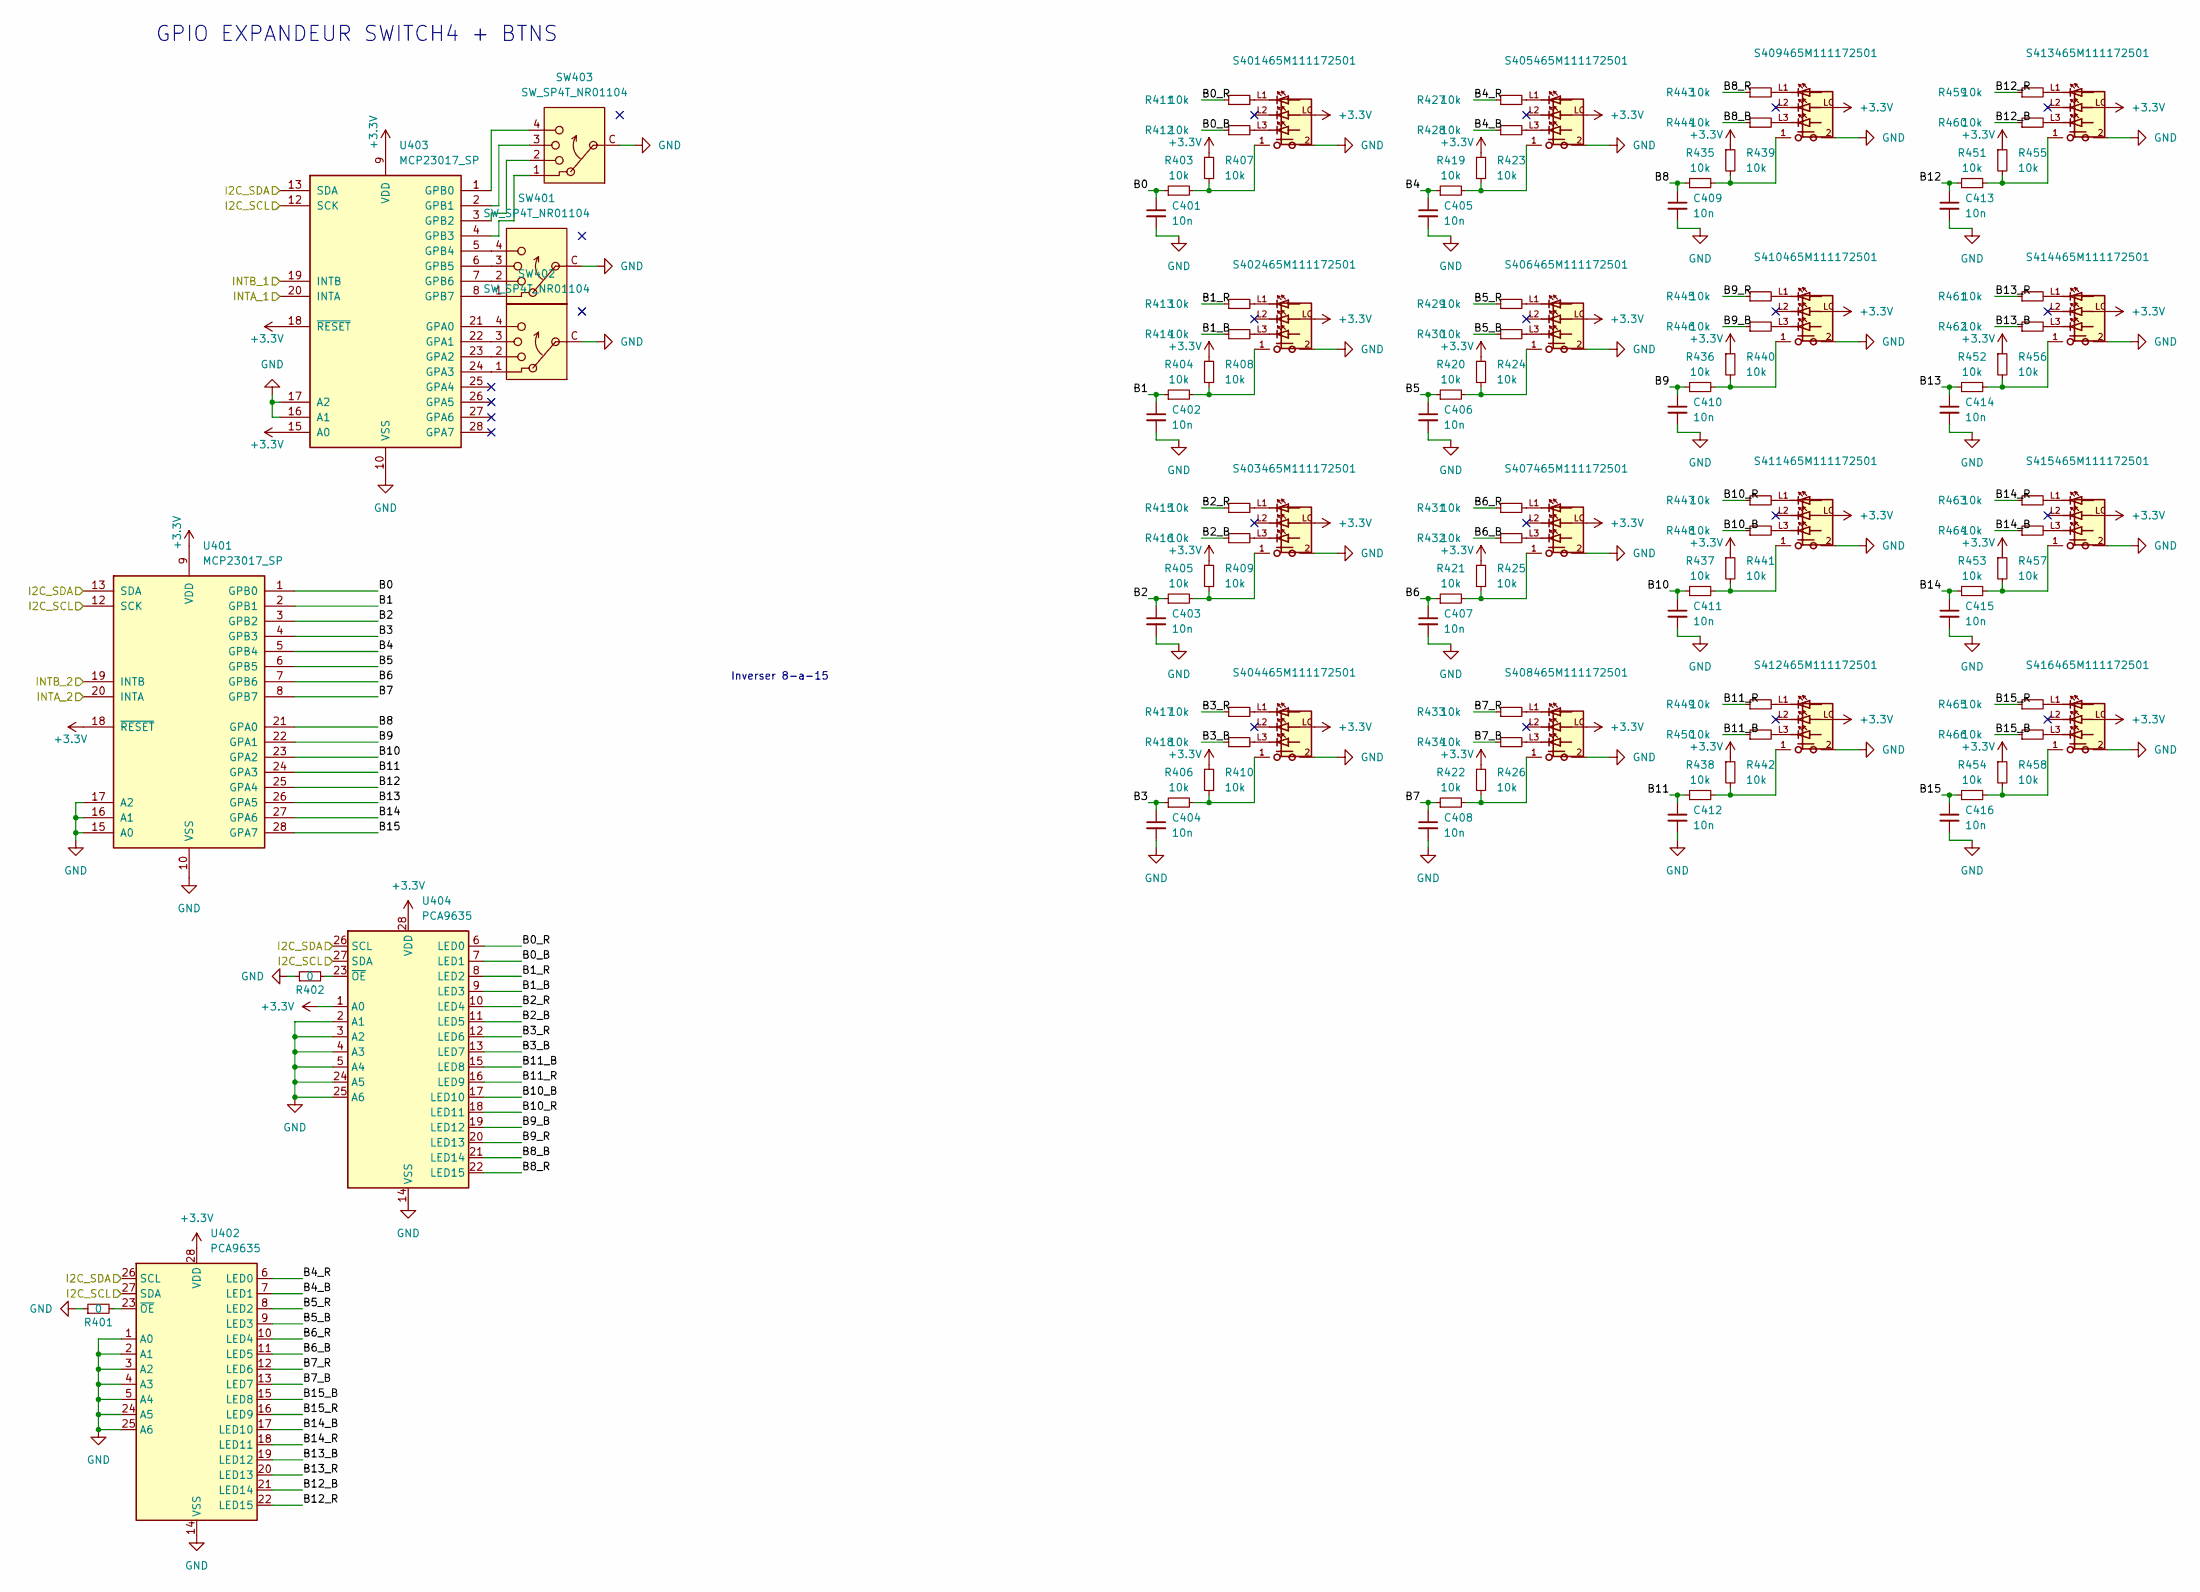
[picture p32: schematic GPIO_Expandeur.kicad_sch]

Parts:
C401, C402, C403, C404, C405, C406, C407, C408, C409, C410, C411, C412, C413, C414, C415, C416: 10n; C_0402_1005Metric
R401, R402: 0; R_0402_1005Metric
R403, R404, R405, R406, R407, R408, R409, R410, R411, R412, R413, R414, R415, R416, R417, R418, R419, R420, R421, R422, R423, R424, R425, R426, R427, R428, R429, R430, R431, R432, R433, R434, R435, R436, R437, R438, R439, R440, R441, R442, R443, R444, R445, R446, R447, R448, R449, R450, R451, R452, R453, R454, R455, R456, R457, R458, R459, R460, R461, R462, R463, R464, R465, R466: 10k; R_0402_1005Metric
S401, S402, S403, S404, S405, S406, S407, S408, S409, S410, S411, S412, S413, S414, S415, S416: 465M111172501; PART-NUMBER 465M111172501
SW401, SW402, SW403: SW_SP4T_NR01104; S-2050
U401, U403: MCP23017_SP; SOIC-28W_7.5x17.9mm_P1.27mm; MPN MCP23017-E/SO
U402, U404: PCA9635; TSSOP-28_4.4x9.7mm_P0.65mm

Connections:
+3.3V: R407.1, R408.1, R409.1, R410.1, R423.1, R424.1, R425.1, R426.1, R439.1, R440.1, R441.1, R442.1, R455.1, R456.1, R457.1, R458.1, S401.LC, S402.LC, S403.LC, S404.LC, S405.LC, S406.LC, S407.LC, S408.LC, S409.LC, S410.LC, S411.LC, S412.LC, S413.LC, S414.LC, S415.LC, S416.LC, U401.9 (VDD), U401.18 (~RESET), U402.28 (VDD), U403.9 (VDD), U403.15 (A0), U403.18 (~RESET), U404.1 (A0), U404.28 (VDD); also elsewhere on the board
/GPIO_Expandeur/B0: C401.1, R403.1, U401.1 (GPB0)
/GPIO_Expandeur/B0_B: R412.1, U404.7 (LED1)
/GPIO_Expandeur/B0_R: R411.1, U404.6 (LED0)
/GPIO_Expandeur/B1: C402.1, R404.1, U401.2 (GPB1)
/GPIO_Expandeur/B1_B: R414.1, U404.9 (LED3)
/GPIO_Expandeur/B1_R: R413.1, U404.8 (LED2)
/GPIO_Expandeur/B2: C403.1, R405.1, U401.3 (GPB2)
/GPIO_Expandeur/B2_B: R416.1, U404.11 (LED5)
/GPIO_Expandeur/B2_R: R415.1, U404.10 (LED4)
/GPIO_Expandeur/B3: C404.1, R406.1, U401.4 (GPB3)
/GPIO_Expandeur/B3_B: R418.1, U404.13 (LED7)
/GPIO_Expandeur/B3_R: R417.1, U404.12 (LED6)
/GPIO_Expandeur/B4: C405.1, R419.1, U401.5 (GPB4)
/GPIO_Expandeur/B4_B: R428.1, U402.7 (LED1)
/GPIO_Expandeur/B4_R: R427.1, U402.6 (LED0)
/GPIO_Expandeur/B5: C406.1, R420.1, U401.6 (GPB5)
/GPIO_Expandeur/B5_B: R430.1, U402.9 (LED3)
/GPIO_Expandeur/B5_R: R429.1, U402.8 (LED2)
/GPIO_Expandeur/B6: C407.1, R421.1, U401.7 (GPB6)
/GPIO_Expandeur/B6_B: R432.1, U402.11 (LED5)
/GPIO_Expandeur/B6_R: R431.1, U402.10 (LED4)
/GPIO_Expandeur/B7: C408.1, R422.1, U401.8 (GPB7)
/GPIO_Expandeur/B7_B: R434.1, U402.13 (LED7)
/GPIO_Expandeur/B7_R: R433.1, U402.12 (LED6)
/GPIO_Expandeur/B8: C409.1, R435.1, U401.21 (GPA0)
/GPIO_Expandeur/B8_B: R444.1, U404.21 (LED14)
/GPIO_Expandeur/B8_R: R443.1, U404.22 (LED15)
/GPIO_Expandeur/B9: C410.1, R436.1, U401.22 (GPA1)
/GPIO_Expandeur/B9_B: R446.1, U404.19 (LED12)
/GPIO_Expandeur/B9_R: R445.1, U404.20 (LED13)
/GPIO_Expandeur/B10: C411.1, R437.1, U401.23 (GPA2)
/GPIO_Expandeur/B10_B: R448.1, U404.17 (LED10)
/GPIO_Expandeur/B10_R: R447.1, U404.18 (LED11)
/GPIO_Expandeur/B11: C412.1, R438.1, U401.24 (GPA3)
/GPIO_Expandeur/B11_B: R450.1, U404.15 (LED8)
/GPIO_Expandeur/B11_R: R449.1, U404.16 (LED9)
/GPIO_Expandeur/B12: C413.1, R451.1, U401.25 (GPA4)
/GPIO_Expandeur/B12_B: R460.1, U402.21 (LED14)
/GPIO_Expandeur/B12_R: R459.1, U402.22 (LED15)
/GPIO_Expandeur/B13: C414.1, R452.1, U401.26 (GPA5)
/GPIO_Expandeur/B13_B: R462.1, U402.19 (LED12)
/GPIO_Expandeur/B13_R: R461.1, U402.20 (LED13)
/GPIO_Expandeur/B14: C415.1, R453.1, U401.27 (GPA6)
/GPIO_Expandeur/B14_B: R464.1, U402.17 (LED10)
/GPIO_Expandeur/B14_R: R463.1, U402.18 (LED11)
/GPIO_Expandeur/B15: C416.1, R454.1, U401.28 (GPA7)
/GPIO_Expandeur/B15_B: R466.1, U402.15 (LED8)
/GPIO_Expandeur/B15_R: R465.1, U402.16 (LED9)
/GPIO_Expandeur/I2C_SCL: U401.12 (SCK), U402.27 (SDA), U403.12 (SCK), U404.27 (SDA); also elsewhere on the board
/GPIO_Expandeur/I2C_SDA: U401.13 (SDA), U402.26 (SCL), U403.13 (SDA), U404.26 (SCL); also elsewhere on the board
/GPIO_Expandeur/INTA_1: U403.20 (INTA); also elsewhere on the board
/GPIO_Expandeur/INTA_2: U401.20 (INTA); also elsewhere on the board
/GPIO_Expandeur/INTB_1: U403.19 (INTB); also elsewhere on the board
/GPIO_Expandeur/INTB_2: U401.19 (INTB); also elsewhere on the board
GND: C401.2, C402.2, C403.2, C404.2, C405.2, C406.2, C407.2, C408.2, C409.2, C410.2, C411.2, C412.2, C413.2, C414.2, C415.2, C416.2, R401.1, R402.1, S401.2, S402.2, S403.2, S404.2, S405.2, S406.2, S407.2, S408.2, S409.2, S410.2, S411.2, S412.2, S413.2, S414.2, S415.2, S416.2, SW401.C (Common), SW402.C (Common), SW403.C (Common), U401.10 (VSS), U401.15 (A0), U401.16 (A1), U401.17 (A2), U402.1 (A0), U402.2 (A1), U402.3 (A2), U402.4 (A3), U402.5 (A4), U402.14 (VSS), U402.24 (A5), U402.25 (A6), U403.10 (VSS), U403.16 (A1), U403.17 (A2), U404.2 (A1), U404.3 (A2), U404.4 (A3), U404.5 (A4), U404.14 (VSS), U404.24 (A5), U404.25 (A6); also elsewhere on the board
unnamed: R403.2, R407.2, S401.1
unnamed: R404.2, R408.2, S402.1
unnamed: R405.2, R409.2, S403.1
unnamed: R406.2, R410.2, S404.1
unnamed: R411.2, S401.L1
unnamed: R412.2, S401.L3
unnamed: R413.2, S402.L1
unnamed: R414.2, S402.L3
unnamed: R415.2, S403.L1
unnamed: R416.2, S403.L3
unnamed: R417.2, S404.L1
unnamed: R418.2, S404.L3
unnamed: R419.2, R423.2, S405.1
unnamed: R420.2, R424.2, S406.1
unnamed: R421.2, R425.2, S407.1
unnamed: R422.2, R426.2, S408.1
unnamed: R427.2, S405.L1
unnamed: R428.2, S405.L3
unnamed: R429.2, S406.L1
unnamed: R430.2, S406.L3
unnamed: R431.2, S407.L1
unnamed: R432.2, S407.L3
unnamed: R433.2, S408.L1
unnamed: R434.2, S408.L3
unnamed: R435.2, R439.2, S409.1
unnamed: R436.2, R440.2, S410.1
unnamed: R437.2, R441.2, S411.1
unnamed: R438.2, R442.2, S412.1
unnamed: R443.2, S409.L1
unnamed: R444.2, S409.L3
unnamed: R445.2, S410.L1
unnamed: R446.2, S410.L3
unnamed: R447.2, S411.L1
unnamed: R448.2, S411.L3
unnamed: R449.2, S412.L1
unnamed: R450.2, S412.L3
unnamed: R451.2, R455.2, S413.1
unnamed: R452.2, R456.2, S414.1
unnamed: R453.2, R457.2, S415.1
unnamed: R454.2, R458.2, S416.1
unnamed: R459.2, S413.L1
unnamed: R460.2, S413.L3
unnamed: R461.2, S414.L1
unnamed: R462.2, S414.L3
unnamed: R463.2, S415.L1
unnamed: R464.2, S415.L3
unnamed: R465.2, S416.L1
unnamed: R466.2, S416.L3
unnamed: R401.2, U402.23 (~OE)
unnamed: SW402.4, U403.21 (GPA0)
unnamed: SW402.3, U403.22 (GPA1)
unnamed: SW402.2, U403.23 (GPA2)
unnamed: SW402.1, U403.24 (GPA3)
unnamed: SW403.4, U403.1 (GPB0)
unnamed: SW403.3, U403.2 (GPB1)
unnamed: SW403.2, U403.3 (GPB2)
unnamed: SW403.1, U403.4 (GPB3)
unnamed: SW401.4, U403.5 (GPB4)
unnamed: SW401.3, U403.6 (GPB5)
unnamed: SW401.2, U403.7 (GPB6)
unnamed: SW401.1, U403.8 (GPB7)
unnamed: R402.2, U404.23 (~OE)

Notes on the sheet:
GPIO EXPANDEUR SWITCH4 + BTNS
Inverser 8-a-15

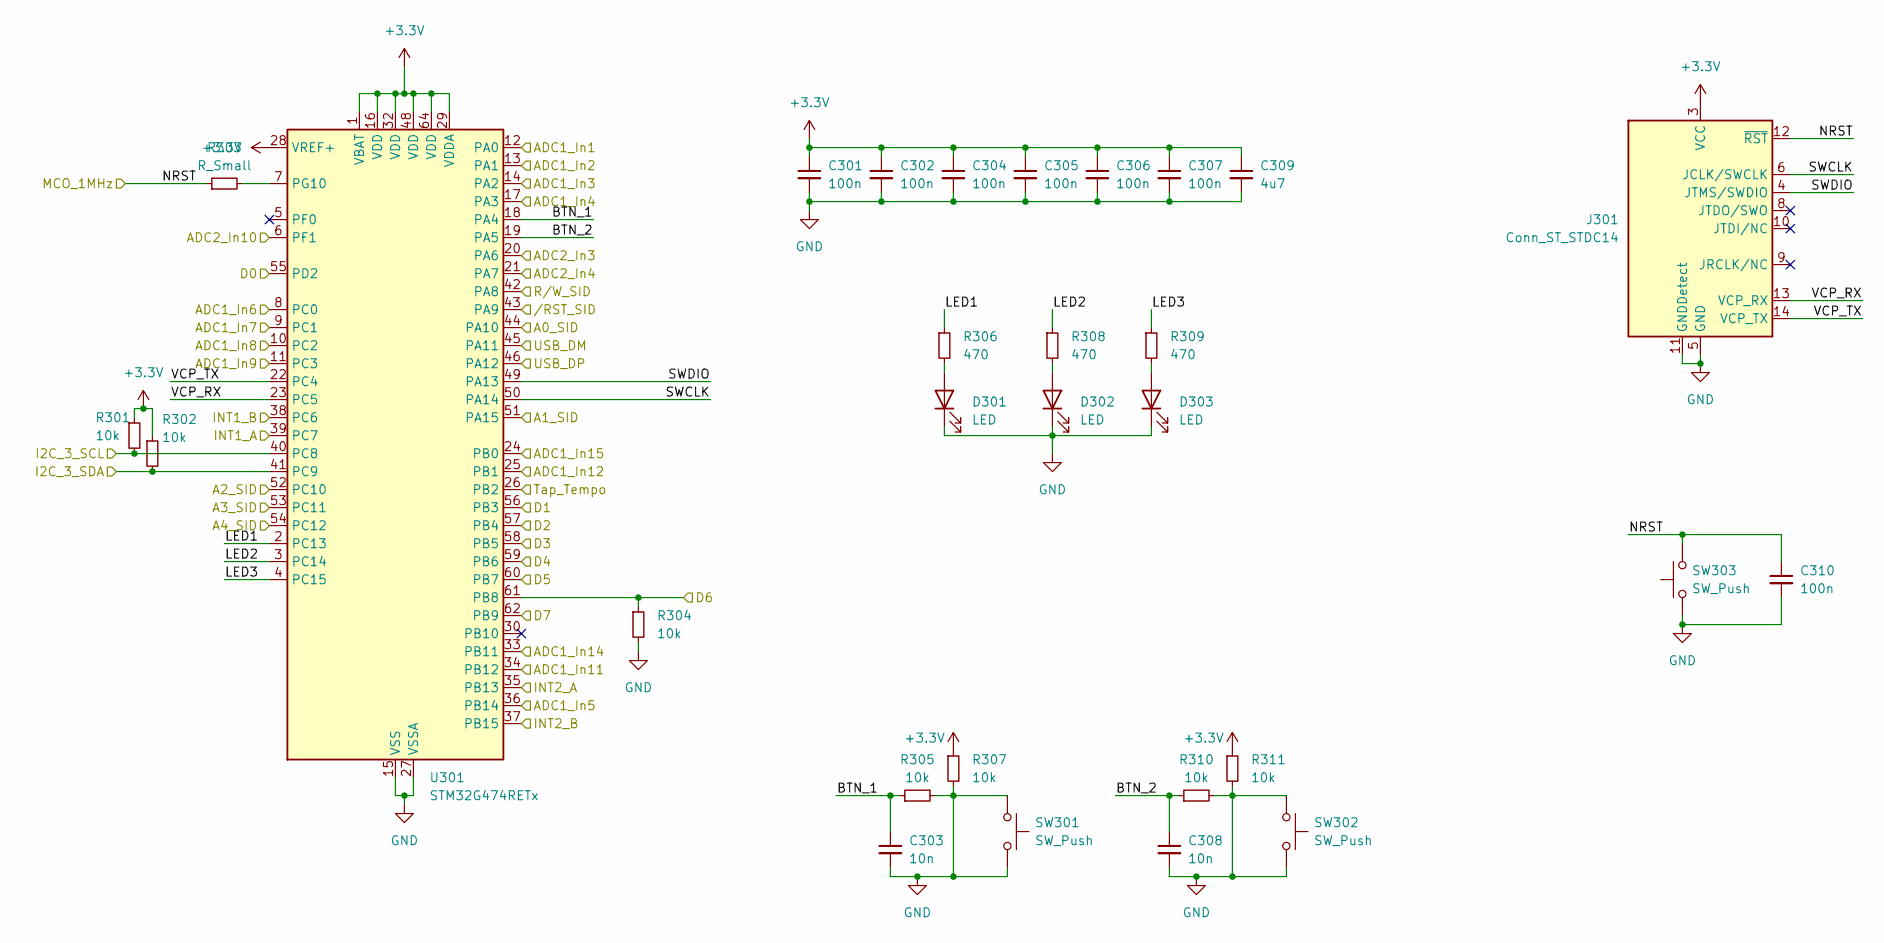
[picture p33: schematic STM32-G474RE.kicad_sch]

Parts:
C301, C302, C304, C305, C306, C307, C310: 100n; C_0402_1005Metric
C303, C308: 10n; C_0402_1005Metric
C309: 4u7; C_0402_1005Metric
D301, D302, D303: LED; LED_0603_1608Metric
J301: Conn_ST_STDC14; PinHeader_2x07_P1.27mm_Vertical_SMD
R301, R302, R304, R305, R307, R310, R311: 10k; R_0402_1005Metric
R303: R_Small; R_0402_1005Metric
R306, R308, R309: 470; R_0402_1005Metric
SW301, SW302, SW303: SW_Push; SW_Push_1P1T_NO_6x6mm_H9.5mm
U301: STM32G474RETx; LQFP-64_10x10mm_P0.5mm

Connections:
+3.3V: C301.1, C302.1, C304.1, C305.1, C306.1, C307.1, C309.1, J301.3 (VCC), R301.1, R302.1, R307.1, R311.1, U301.1 (VBAT), U301.16 (VDD), U301.28 (VREF+), U301.29 (VDDA), U301.32 (VDD), U301.48 (VDD), U301.64 (VDD); also elsewhere on the board
/GPIO_Expandeur/I2C_SCL: R301.2, U301.40 (PC8); also elsewhere on the board
/GPIO_Expandeur/I2C_SDA: R302.2, U301.41 (PC9); also elsewhere on the board
/GPIO_Expandeur/INTA_1: U301.39 (PC7); also elsewhere on the board
/GPIO_Expandeur/INTA_2: U301.35 (PB13); also elsewhere on the board
/GPIO_Expandeur/INTB_1: U301.38 (PC6); also elsewhere on the board
/GPIO_Expandeur/INTB_2: U301.37 (PB15); also elsewhere on the board
/MOS6581/A0: U301.44 (PA10); also elsewhere on the board
/MOS6581/A1: U301.51 (PA15); also elsewhere on the board
/MOS6581/A2: U301.52 (PC10); also elsewhere on the board
/MOS6581/A3: U301.53 (PC11); also elsewhere on the board
/MOS6581/A4: U301.54 (PC12); also elsewhere on the board
/MOS6581/D0: U301.55 (PD2); also elsewhere on the board
/MOS6581/D1: U301.56 (PB3); also elsewhere on the board
/MOS6581/D2: U301.57 (PB4); also elsewhere on the board
/MOS6581/D3: U301.58 (PB5); also elsewhere on the board
/MOS6581/D4: U301.59 (PB6); also elsewhere on the board
/MOS6581/D5: U301.60 (PB7); also elsewhere on the board
/MOS6581/D6: R304.1, U301.61 (PB8); also elsewhere on the board
/MOS6581/D7: U301.62 (PB9); also elsewhere on the board
/MOS6581/MOS6581_Read/Write: U301.42 (PA8); also elsewhere on the board
/MOS6581//Reset: U301.43 (PA9); also elsewhere on the board
/PSU/USB_DM: U301.45 (PA11); also elsewhere on the board
/PSU/USB_DP: U301.46 (PA12); also elsewhere on the board
/Potar/Filter_Freq_pot: U301.6 (PF1); also elsewhere on the board
/Potar/Filter_Res_pot: U301.21 (PA7); also elsewhere on the board
/Potar/Pitch_Main_pot: U301.13 (PA1); also elsewhere on the board
/Potar/Pitch_octave_pot: U301.12 (PA0); also elsewhere on the board
/Potar/Voice1_Attack_pot: U301.17 (PA3); also elsewhere on the board
/Potar/Voice1_Decay_pot: U301.36 (PB14); also elsewhere on the board
/Potar/Voice1_PW_pot: U301.14 (PA2); also elsewhere on the board
/Potar/Voice1_Release_pot: U301.8 (PC0); also elsewhere on the board
/Potar/Voice2_Attack_pot: U301.10 (PC2); also elsewhere on the board
/Potar/Voice2_Decay_pot: U301.11 (PC3); also elsewhere on the board
/Potar/Voice2_PW_pot: U301.9 (PC1); also elsewhere on the board
/Potar/Voice2_Release_pot: U301.34 (PB12); also elsewhere on the board
/Potar/Voice3_Attack_pot: U301.33 (PB11); also elsewhere on the board
/Potar/Voice3_Decay_pot: U301.24 (PB0); also elsewhere on the board
/Potar/Voice3_PW_pot: U301.25 (PB1); also elsewhere on the board
/Potar/Voice3_Release_pot: U301.20 (PA6); also elsewhere on the board
/STM32-G474RE/BTN_1: C303.1, R305.1, U301.18 (PA4)
/STM32-G474RE/BTN_2: C308.1, R310.1, U301.19 (PA5)
/STM32-G474RE/LED1: R306.1, U301.2 (PC13)
/STM32-G474RE/LED2: R308.1, U301.3 (PC14)
/STM32-G474RE/LED3: R309.1, U301.4 (PC15)
/STM32-G474RE/NRST: C310.1, J301.12 (~RST), R303.1, SW303.2; also elsewhere on the board
/STM32-G474RE/SWCLK: J301.6 (JCLK/SWCLK), U301.50 (PA14)
/STM32-G474RE/SWDIO: J301.4 (JTMS/SWDIO), U301.49 (PA13)
/STM32-G474RE/Tap_Tempo: U301.26 (PB2); also elsewhere on the board
/STM32-G474RE/VCP_RX: J301.13 (VCP_RX), U301.23 (PC5)
/STM32-G474RE/VCP_TX: J301.14 (VCP_TX), U301.22 (PC4)
GND: C301.2, C302.2, C303.2, C304.2, C305.2, C306.2, C307.2, C308.2, C309.2, C310.2, D301.1 (K), D302.1 (K), D303.1 (K), J301.5 (GND), J301.7 (GND), J301.11 (GNDDetect), R304.2, R305.2, R307.2, R310.2, R311.2, SW301.1, SW301.2, SW302.1, SW302.2, SW303.1, U301.15 (VSS), U301.27 (VSSA), U301.31 (VSS), U301.47 (VSS), U301.63 (VSS); also elsewhere on the board
unnamed: D301.2 (A), R306.2
unnamed: D302.2 (A), R308.2
unnamed: D303.2 (A), R309.2
unnamed: R303.2, U301.7 (PG10)

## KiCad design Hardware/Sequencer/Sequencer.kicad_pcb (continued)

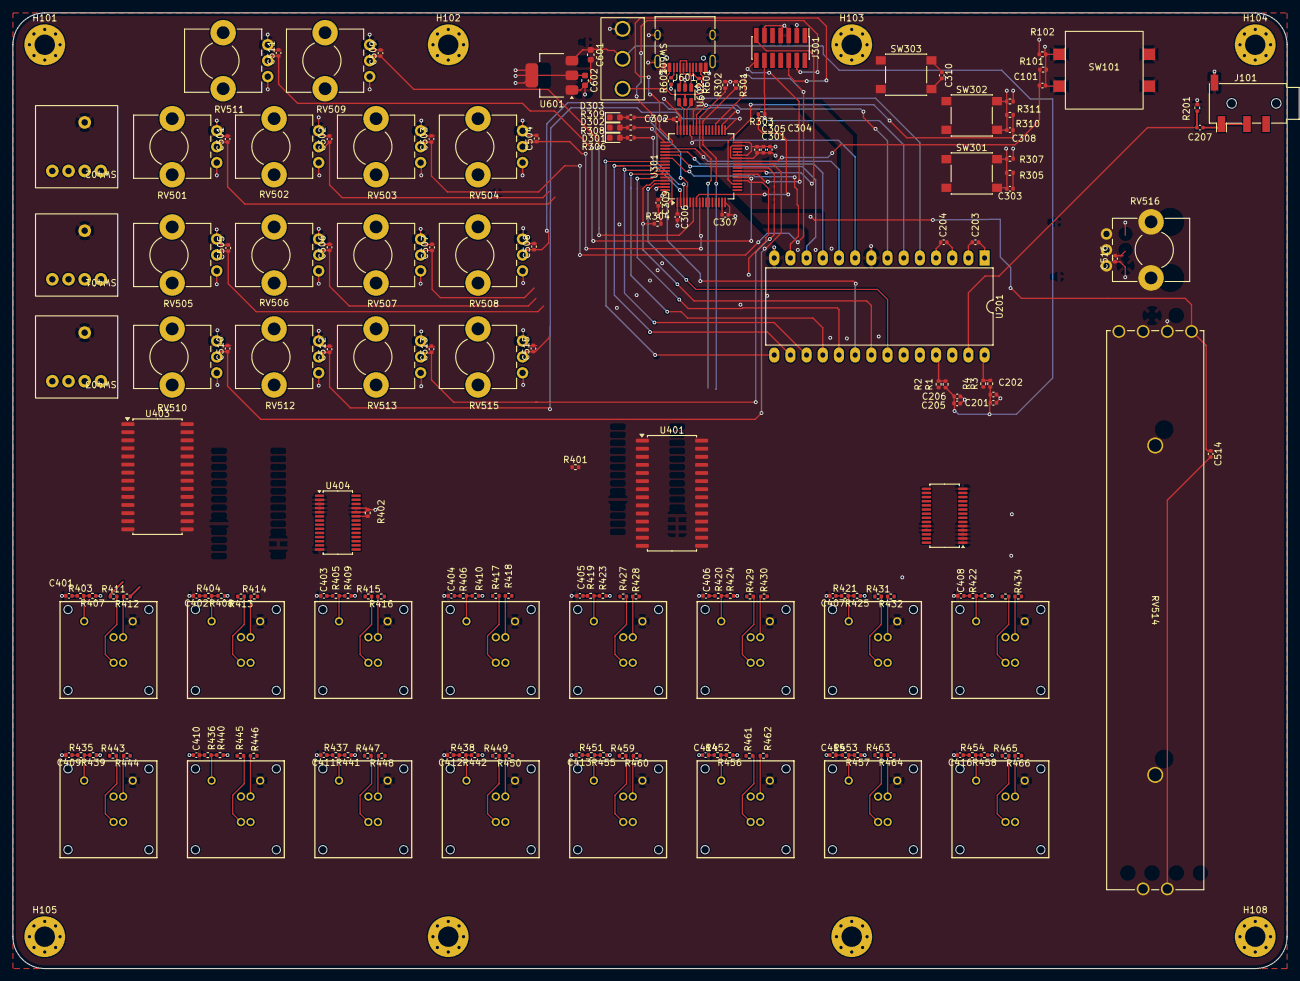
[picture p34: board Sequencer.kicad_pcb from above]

Board: 4 copper layers, 200.0 x 150.0 mm, 200 parts (0 on the bottom side), 181 nets.

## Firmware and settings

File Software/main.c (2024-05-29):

#include <stdio.h>
#include <main.h>
#include <classes.h>
#include <math.h>

#define PCA9635_ADDRESS 0x60 // adresse A0 A1 A2=0
#define PCA9635_ADDRESS 0x61 // adresse A0=3.3V A1=A2=0 cf docu



//Initialisation des structures (StepInit() eventuellement)
//Voice
struct Voice voice1= {0,0,0,0,0};
struct Voice voice2= {0,0,0,0,0};
struct Voice voice3= {0,0,0,0,0};

//Step
struct step1 {int state;int note;int octave;struct Voice voice1; struct Voice voice2; struct Voice voice3;};
struct step2 {int state;int note;int octave;struct Voice voice1; struct Voice voice2; struct Voice voice3;};
struct step3 {int state;int note;int octave;struct Voice voice1; struct Voice voice2; struct Voice voice3;};
struct step4 {int state;int note;int octave;struct Voice voice1; struct Voice voice2; struct Voice voice3;};
struct step5 {int state;int note;int octave;struct Voice voice1; struct Voice voice2; struct Voice voice3;};
struct step6 {int state;int note;int octave;struct Voice voice1; struct Voice voice2; struct Voice voice3;};
struct step7 {int state;int note;int octave;struct Voice voice1; struct Voice voice2; struct Voice voice3;};
struct step8 {int state;int note;int octave;struct Voice voice1; struct Voice voice2; struct Voice voice3;};
struct step9 {int state;int note;int octave;struct Voice voice1; struct Voice voice2; struct Voice voice3;};
struct step10 {int state;int note;int octave;struct Voice voice1; struct Voice voice2; struct Voice voice3;};
struct step11 {int state;int note;int octave;struct Voice voice1; struct Voice voice2; struct Voice voice3;};
struct step12 {int state;int note;int octave;struct Voice voice1; struct Voice voice2; struct Voice voice3;};
struct step13 {int state;int note;int octave;struct Voice voice1; struct Voice voice2; struct Voice voice3;};
struct step14 {int state;int note;int octave;struct Voice voice1; struct Voice voice2; struct Voice voice3;};
struct step15 {int state;int note;int octave;struct Voice voice1; struct Voice voice2; struct Voice voice3;};
struct step16 {int state;int note;int octave;struct Voice voice1; struct Voice voice2; struct Voice voice3;};

struct Step step1={0,0,0,{0,0,0,0,0},{0,0,0,0,0},{0,0,0,0,0}};
struct Step step2={0,0,0,{0,0,0,0,0},{0,0,0,0,0},{0,0,0,0,0}};
struct Step step3={0,0,0,{0,0,0,0,0},{0,0,0,0,0},{0,0,0,0,0}};
struct Step step4={0,0,0,{0,0,0,0,0},{0,0,0,0,0},{0,0,0,0,0}};
struct Step step5={0,0,0,{0,0,0,0,0},{0,0,0,0,0},{0,0,0,0,0}};
struct Step step6={0,0,0,{0,0,0,0,0},{0,0,0,0,0},{0,0,0,0,0}};
struct Step step7={0,0,0,{0,0,0,0,0},{0,0,0,0,0},{0,0,0,0,0}};
struct Step step8={0,0,0,{0,0,0,0,0},{0,0,0,0,0},{0,0,0,0,0}};
struct Step step9={0,0,0,{0,0,0,0,0},{0,0,0,0,0},{0,0,0,0,0}};
struct Step step10={0,0,0,{0,0,0,0,0},{0,0,0,0,0},{0,0,0,0,0}};
struct Step step11={0,0,0,{0,0,0,0,0},{0,0,0,0,0},{0,0,0,0,0}};
struct Step step12={0,0,0,{0,0,0,0,0},{0,0,0,0,0},{0,0,0,0,0}};
struct Step step13={0,0,0,{0,0,0,0,0},{0,0,0,0,0},{0,0,0,0,0}};
struct Step step14={0,0,0,{0,0,0,0,0},{0,0,0,0,0},{0,0,0,0,0}};
struct Step step15={0,0,0,{0,0,0,0,0},{0,0,0,0,0},{0,0,0,0,0}};
struct Step step16={0,0,0,{0,0,0,0,0},{0,0,0,0,0},{0,0,0,0,0}};




//Filter
//Paramètres initiaux
struct filter {int mode;int fres;int res;};

struct Filter filter={0,0,0};
//LED
//Paramètres initiaux de LED
struct led1 {int IDred;int IDgreen;int red;int green;int dimm;};
struct led2 {int IDred;int IDgreen;int red;int green;int dimm;};
struct led3 {int IDred;int IDgreen;int red;int green;int dimm;};
struct led4 {int IDred;int IDgreen;int red;int green;int dimm;};
struct led5 {int IDred;int IDgreen;int red;int green;int dimm;};
struct led6 {int IDred;int IDgreen;int red;int green;int dimm;};
struct led7 {int IDred;int IDgreen;int red;int green;int dimm;};
struct led8 {int IDred;int IDgreen;int red;int green;int dimm;};
struct led9 {int IDred;int IDgreen;int red;int green;int dimm;};
struct led10 {int IDred;int IDgreen;int red;int green;int dimm;};
struct led11 {int IDred;int IDgreen;int red;int green;int dimm;};
struct led12 {int IDred;int IDgreen;int red;int green;int dimm;};
struct led13 {int IDred;int IDgreen;int red;int green;int dimm;};
struct led14 {int IDred;int IDgreen;int red;int green;int dimm;};
struct led15 {int IDred;int IDgreen;int red;int green;int dimm;};
struct led16 {int IDred;int IDgreen;int red;int green;int dimm;};

struct Led led1={0,0,0,0,0};
struct Led led2={0,0,0,0,0};
struct Led led3={0,0,0,0,0};
struct Led led4={0,0,0,0,0};
struct Led led5={0,0,0,0,0};
struct Led led6={0,0,0,0,0};
struct Led led7={0,0,0,0,0};
struct Led led8={0,0,0,0,0};
struct Led led9={0,0,0,0,0};
struct Led led10={0,0,0,0,0};
struct Led led11={0,0,0,0,0};
struct Led led12={0,0,0,0,0};
struct Led led13={0,0,0,0,0};
struct Led led14={0,0,0,0,0};
struct Led led15={0,0,0,0,0};
struct Led led16={0,0,0,0,0};


//Convertisseur Décimal->Binaire
int decimal_To_binary(int n, int binaryArray[8])    // binaryArray[N] où N=8 ou N=16 pour ...
{
	if (n>=256)
	{
		return 0;
	}
	for (int i = 7; i >= 0; i--)
	{
		if (n>=pow(2,i))
		{
			binaryArray[i] = 1 ;
		}
		else
		{
			binaryArray[i]=0 ;
		}
	}
	return binaryArray;
}




// Code I2C
int main(void)
{
	HAL_Init();
	MX_GPIO_Init();
	MX_I2C1_Init();
	uint8_t button_state_a=0;
	uint8_t button_state_b=0;
	HAL_IncTick();
	I2C_HandleTypeDef hi2c1;
	/*
	struct Sequence {struct Step note1 ;struct Step note2 ;struct Step note3 ;struct Step note4; struct Step note5 ;struct Step note6 ;struct Step note7 ;struct Step note8 ;struct Step note9 ;struct Step note10 ;struct Step note11 ;struct Step note12 ;struct Step note13 ;struct Step note14 ;struct Step note15 ;struct Step note16;};
	struct Sequence sequence={ step1 , step2 , step3 , step4 , step5 , step6 , step7 , step8 , step9 , step10 , step11 , step12 , step13 , step14 , step15 , step16};
	*/
	while(1){
		HAL_I2C_Master_Receive(&hi2c1, (0x60<<1), &button_state_a , 1 , HAL_MAX_DELAY);
		HAL_I2C_Master_Receive(&hi2c1, (0x61<<1), &button_state_b , 1 , HAL_MAX_DELAY);

		for (int i=0; i<8; i++)
		{
			if ((button_state_a & (1<<i))==1)
			{
				int debut;
				int fin;
				int duree_appui;
				debut=HAL_GetTick();    // en ms
				while (button_state_a==1)
				{
					fin=HAL_GetTick();   // en ms
					duree_appui= fin-debut;
					if (duree_appui>=1000)
					{
						editstep(i);
					}
				}
				if (duree_appui<1000)
				{
					if (i==0){
						step1.state=1-step1.state;
					}
					if (i==1){
						step2.state=1-step2.state;
					}
					if (i==2){
						step3.state=1-step3.state;
					}
					if (i==3){
						step4.state=1-step4.state;
					}
					if (i==4){
						step5.state=1-step5.state;
					}
					if (i==5){
						step6.state=1-step6.state;
					}
					if (i==6){
						step7.state=1-step7.state;
					}
					if (i==7){
						step8.state=1-step8.state;
					}


				}
			}
		}

		for (int i=0; i<8; i++)
		{
					if ((button_state_b & (1<<i))==1)
					{
						int debut;
						int fin;
						int duree_appui;
						debut=HAL_GetTick();    // en ms
						while (button_state_b==1)
						{
							fin=HAL_GetTick();   // en ms
							duree_appui= fin-debut;
							if (duree_appui>=1000)
							{
								editstep(i+8);
							}
						}
						if (duree_appui<1000)
						{
							if (i==0){
								step9.state=1-step9.state;
							}
							if (i==1){
								step10.state=1-step10.state;
							}
							if (i==2){
								step11.state=1-step11.state;
							}
							if (i==3){
								step12.state=1-step12.state;
							}
							if (i==4){
								step13.state=1-step13.state;
							}
							if (i==5){
								step14.state=1-step14.state;
							}
							if (i==6){
								step15.state=1-step15.state;
							}
							if (i==7){
								step16.state=1-step16.state;
							}

						}
					}
		}
	}
}



//Jouer une note
//pitch(a,b) où a est compris entre 1 et 12 (note) et b compris entre 0 et 7 (octave)

int editstep(int i){
	ADC_HandleTypeDef hadc1;

	//Recuperation des valeurs des potentiometres de modification de pitch et param
//	voice1.voiceMode=HAL_   ;
//	voice1.pw=HAL_  ;
//	voice1.attack=HAL_   ;
//	voice1.decay=HAL_   ;
//	voice1.release=HAL_   ;
	int a;
	int b;
	a=HAL_ADC_GetValue(&hadc1)  ; //note
	HAL_ADC_PollForConversion(&hadc1, HAL_MAX_DELAY);
	b=HAL_ADC_GetValue(&hadc1) ;  //octave

	//Enregistrement du pitch
	if (i==0){
		step1.note=a;
		step1.octave=b;
		step1.voice1=voice1;
	}
	if (i==1){
		step2.note=a;
		step2.octave=b;
		step2.voice1=voice1;
	}
	if (i==2){
		step3.note=a;
		step3.octave=b;
		step3.voice1=voice1;
	}
	if (i==3){
		step4.note=a;
		step4.octave=b;
		step4.voice1=voice1;
	}
	if (i==4){
		step5.note=a;
		step5.octave=b;
		step5.voice1=voice1;
	}
	if (i==5){
		step6.note=a;
		step6.octave=b;
		step6.voice1=voice1;
	}
	if (i==6){
		step7.note=a;
		step7.octave=b;
		step7.voice1=voice1;
	}
	if (i==7){
		step8.note=a;
		step8.octave=b;
		step8.voice1=voice1;
	}
	if (i==8){
		step9.note=a;
		step9.octave=b;
		step9.voice1=voice1;
	}
	if (i==9){
		step10.note=a;
		step10.octave=b;
		step10.voice1=voice1;
	}
	if (i==10){
		step11.note=a;
		step11.octave=b;
		step11.voice1=voice1;
	}
	if (i==11){
		step12.note=a;
		step12.octave=b;
		step12.voice1=voice1;
	}
	if (i==12){
		step13.note=a;
		step13.octave=b;
		step13.voice1=voice1;
	}
	if (i==13){
		step14.note=a;
		step14.octave=b;
		step14.voice1=voice1;
	}
	if (i==14){
		step15.note=a;
		step15.octave=b;
		step15.voice1=voice1;
	}
	if (i==15){
		step16.note=a;
		step16.octave=b;
		step16.voice1=voice1;
	}

}

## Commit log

2024-02-29 création de dossiers
2024-02-29 modifs cahier des charges
2024-03-14 update schematic
    [GPIO_Expandeur.kicad_sch, MOS6581.kicad_sch, PSU.kicad_sch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]
2024-03-14 ADC connexion
2024-03-14 Régu
    [PSU.kicad_sch]
2024-03-14 project add
    [MOS6581.kicad_sch, Potar.kicad_sch]
2024-03-28 Beaucoup de changements sur le pcb
    Alim corrigée, ajout de l'USB C
    Sonde sur le processeur + linkage USB
    Rajout des boutons (465M111...)
    [GPIO_Expandeur.kicad_sch, MOS6581.kicad_sch, PSU.kicad_sch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]
2024-03-28 pcb créé pour les estimations des dimensions de la carte
2024-03-28 actualisation pcb de test
    [Sequencer.kicad_pcb]
2024-03-30 update dimension pcb, footprint
    [GPIO_Expandeur.kicad_sch, MOS6581.kicad_sch, PSU.kicad_sch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]
2024-04-01 much changes everywhere
    [GPIO_Expandeur.kicad_sch, MOS6581.kicad_sch, Sequencer.kicad_sch]
2024-04-04 Create journal_de_bord.md
    création journal de bord
2024-04-04 PCB PCB
    [Sequencer.kicad_pcb]
2024-04-04 SCHEMA CORRECTION LED
    [GPIO_Expandeur.kicad_sch, Sequencer.kicad_sch]
2024-04-04 update pcb
    [GPIO_Expandeur.kicad_sch, MOS6581.kicad_sch, PSU.kicad_sch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]
2024-04-04 PCB PCB PCB
    [MOS6581.kicad_sch, Sequencer.kicad_pcb]
2024-04-04 PCB uP bientot fini
    [MOS6581.kicad_sch, Sequencer.kicad_pcb]
2024-04-04 PCB TERMINE (sauf erreurs bizarres et optimisation)
    [GPIO_Expandeur.kicad_sch]
2024-04-05 finalize pcb
    [Sequencer-B_Cu.gbr, Sequencer-B_Mask.gbr, Sequencer-B_Paste.gbr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]
2024-04-25 Design du socle 3D
    [Boitier_sequenceur v3.f3d]
2024-04-25 ajout de 2 formats 3D pour le design du boitier
    [Boitier_sequenceur v3.3mf, Boitier_sequenceur v3.stl]
2024-05-02 changement impression 3D
    [Boitier_sequenceur v3.3mf, Boitier_sequenceur v3.f3d, Boitier_sequenceur v3.stl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]
2024-05-16 plans 3D
    [Boitier_sequenceur v6.stl, Joints sequenceur.stl]
2024-05-28 maj Livrables et 3D
    [capuchon_potar_lineaire_sequenceur v4.stl, capuchon_potar_lineaire_sequenceur v7.stl, capuchon_potar_sequenceur v1.stl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]
